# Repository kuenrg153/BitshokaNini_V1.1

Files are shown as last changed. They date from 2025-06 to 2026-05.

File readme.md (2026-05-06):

```
Open Source is Intrinsic to Bitcoin
```
# The Bitshoka Nini V1.1
The Bitshoka Nini V1.1 is based off of the Bitaxe Gamma EXCEPT it uses the KF1950 ASIC from MicroBT / Whatsminer.
Huge shoutout to skot for all the work he did create this ecosystem!
The primary aim Bitshoka Nini is to bring microBT ASICs to the Bitaxe ecosystem. A secondary goal is to make a low cost and readily available Bitaxe variant in Africa.
We hope that this is the first of a number of contributions the Bitshoka team can make to the bitcoin network.
Shoka is "axe" and Nini is "what" in Swahili.

# The bitaxe
bitaxe is a fully open source Bitcoin ASIC miner aimed at decentralizing mining. 

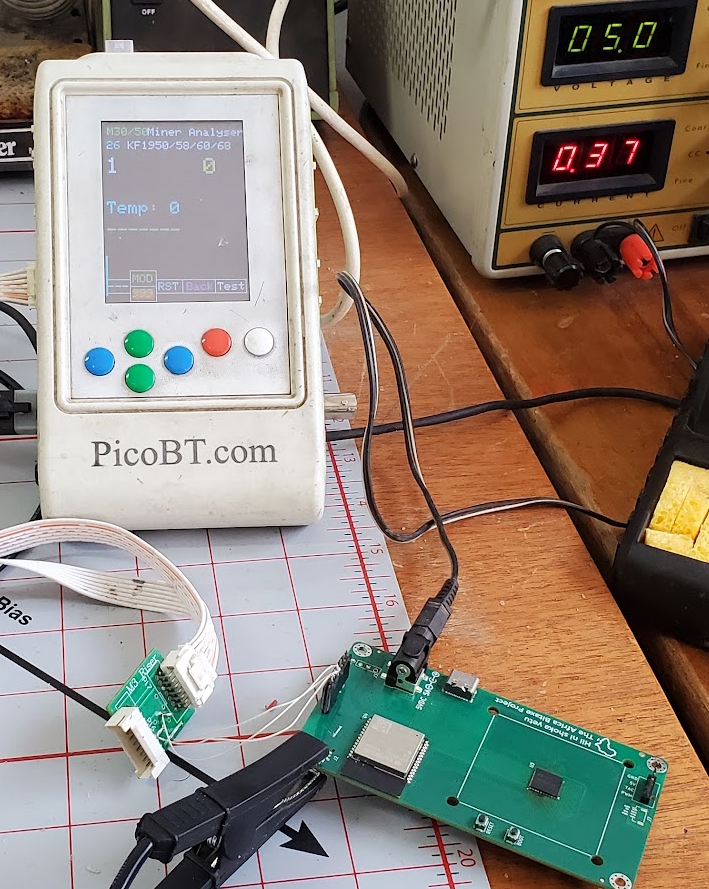
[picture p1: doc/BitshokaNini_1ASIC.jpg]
bitaxeUltra assembled


## Goals
- **Easy**: Just plug it in and mine Bitcoin over WiFi. No external computer needed.
- **Practical**: low cost, low noise, low power, low maintenance. You can run this at home.
- **ASIC Power**: High efficiency and hashrate, based on the latest and greatest Application Specific Integrated Circuits.
- **Versatile**: Mine to any StratumV1 pool, Lottery mine, Solo mine, Or hack it to do whatever you want.
- **Bitcoin Ethos**: Fully open source, permissionless and decentralized to support the worldwide freedom money.

## ASIC
At the heart of the bitaxeGamma is a BM1370 Bitcoin mining ASIC from the Antminer S21 Pro from Bitmain. It's not open source.

- Bitmain claims the BM1370 has 15 J/TH efficiency. We can get pretty close to that with the BitaxeGamma
- The Antminer S21 Pro has a nominal hashrate of 234 TH/s. There are 3 hashboards with 65 chips each, for a total of 195 chips. The bitaxeGamma has a single one of these chips. That means _about_ 1.2 TH/s per bitaxeGamma. Initial testing looks good!
- The BM1370 is brand new and isn't available individually yet. The best place to get these chips is right out of a S21 Pro.
- The BM1370 has a different footprint and pinout from the BM1368, BM1366, BM1397 and BM1387 in previous bitaxe.

## Current Status
- BitaxeGamma 600 is working well and has been released!
- In addition to higher hashrate, the Gamma also uses more power. Please pay attemtion to hash frequency and voltage settings as it's much easier to overheat, especially when using the stock heatsink and fan.
- BM1370 firmware support has been added to [esp-miner](https://github.com/skot/esp-miner)
- Be sure to check the [HW issues](https://github.com/skot/bitaxe/issues) for known bugs, reworks and errata.
- This is an _advanced_ build! You can do it, but if you're not looking for a project, it might be best to buy one pre-assembled from one of the [many sellers](https://bitaxe.org/legit.html). Check [Skot's method](assembly.md) of hand assembling PCBs.

## PCB Hardware
This repo contains all of the design files for the PCB. [KiCAD](https://www.kicad.com) software is used. There is a BOM file for all of the components that get soldered to the PCB. 

- Order PCBs from your favorite PCB shop, like [JLCPCB](https://jlcpcb.com), [SeeedStudio](https://www.seeedstudio.com/fusion_pcb.html), or [PCBWay](https://www.pcbway.com)
    - Gerbers are in the `Manufacturing Files` dir. PCBs are 4-layer, 6mil trace/space and 0.3mm hole compatible. 1oz outer / 0.5oz inner layer thickness works well.
    - Make sure to order stencils too. These are the "paste" layers in the gerbers folder. one for top and one for bottom.
- All PCB parts except the ASIC are available from [DigiKey](https://www.digikey.com/en/products) and others. You can find Digikey part numbers on the DK tab of the BOM

## Extra Hardware
There are a few other hardware components that are needed for a complete bitaxe.

- **Heatsink**
	- [40x40mm heatsink and 5V fan](https://www.aliexpress.com/item/2251832861666365.html) from a random AliExpress seller. The fans are crap, but the heatsinks are good.  
- **Fan**
	- You **must** have active cooling on the bitaxe. The heatsink alone is not enough.
	- The Bitaxe has a connector for a 4pin, 5V PWM fan. 40mm square, 20mm thick fans work nicely with the suggested heatsink. Make sure to get a 5V fan! 12V spin, but slowly overheating your Bitaxe..
	- Upgrade your fan with the [Noctua NF-A4x10](https://noctua.at/en/nf-a4x10-5v-pwm) 5V 4-Pin fan for a much more pleasant experience.
- **Thermal compound**
	- Use a good quality thermal compound between the heatsink and ASIC. [Thermal Grizzly Kryonaut](https://www.amazon.com/Thermal-Grizzly-Kryonaut-Grease-Paste/dp/B011F7W3LU) has been known to work well.  
- **Display**
	- Supports 0.91" SSD1306-based I2C OLED Module. [Example Amazon seller](https://www.amazon.com/gp/product/B08ZY4YBHL). Make sure to get the male pins to interface with the Bitaxe PCB. 
- **Power Supply**
	- **5V DC Only!** Anything else will damage the Bitaxe. Be careful and double-check your power supply is 5V. Many other voltage power supplies use the same connector.
	- The power supply needs to supply in excess of 4A (20W) and not drop below 5V. Often times you have to use a power supply rated for 25-30W to get this!
 		- The [Meanwell GST60A05-P1J](https://www.digikey.com/en/products/detail/mean-well-usa-inc/GST60A05-P1J/7703709) at 30 Watts is the cadillac of 5V PSUs and is working well with the Gamma.  
	- The bitaxe uses a 5.5x2.1mm, center-positive barrel jack. 5.5x2.5mm plugs have been known to work.
- **Stand**
	- The PCB has corner mounting holes. You're going to want a stand to mount your Bitaxe. Many excellent 3D printed designs are available.

## Firmware
- The [ESP-Miner](https://github.com/skot/ESP-Miner) has initial support for the BM1370 ASIC. Improvements are ongoing.

### ESP32 Programming Requirements
- As of the bitaxeUltra, all ESP32 programming is done through a USB-C cable and connector on the bitaxe. See [ESP-Miner](https://github.com/skot/ESP-Miner) for more details.

## More Information
- Project page at [bitaxe.org](https://bitaxe.org)
- [Open Source Miners United](discord.gg/osmu) Discord chat
- [building.md](building.md) for PCB ordering tips
- [assembly.md](assembly.md) for assembly tips

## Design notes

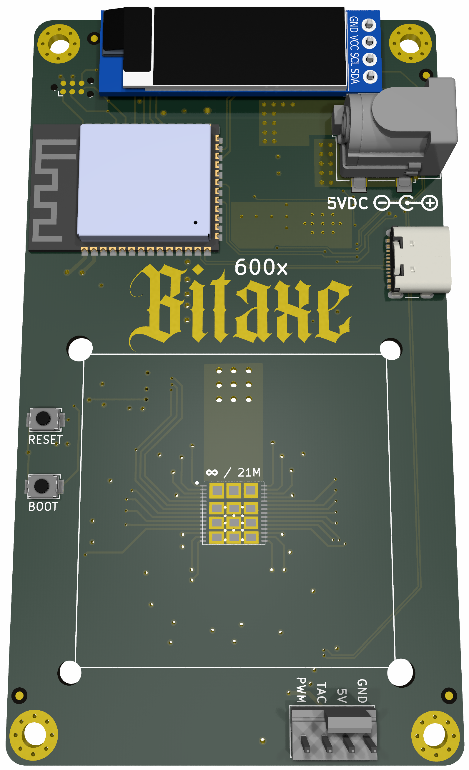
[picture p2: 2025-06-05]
doc/render.png

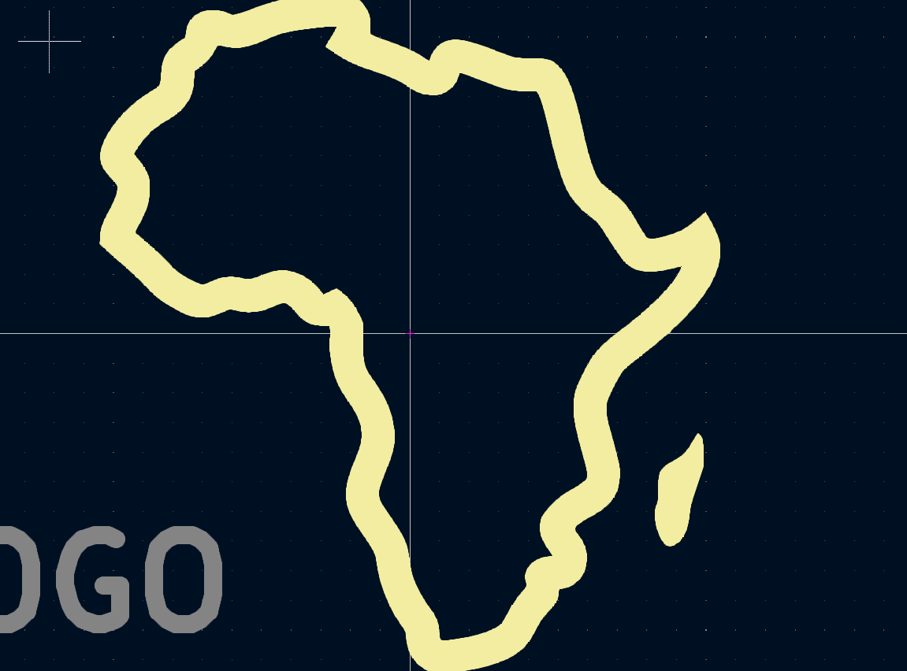
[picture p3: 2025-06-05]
Africa Map Only.png

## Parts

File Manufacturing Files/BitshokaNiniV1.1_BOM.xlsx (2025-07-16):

Comment | Reference | Footprint | PARTNO
0 | R6 R10 R17 R19 R20 R26 R27 R75 R76 R77 R78 R79 | Resistor_SMD:R_0402_1005Metric | CSR1206FT1R00
0 | R35 R73 | Resistor_SMD:R_0402_1005Metric | DNP
100pF | C13 | Capacitor_SMD:C_0402_1005Metric | 885012005013
470pF | C50 | Capacitor_SMD:C_0402_1005Metric | CL05B471KB5NNNC
1000pF | C11 | Capacitor_SMD:C_0402_1005Metric | CC0805KRX7R9BB102
2200pF | C9 | Capacitor_SMD:C_0402_1005Metric | GRM155R61H222KA01D
4700pF | C6 | Capacitor_SMD:C_0402_1005Metric | GRM155R71E472KA01D
72nH | L1 | FP0805R1 | FP0805R1-R07-R
0.1uF | C8 C25 C27 C28 C29 C31 C32 C34 C37 C38 C47 C49 C52 C53 C73 C74 | Capacitor_SMD:C_0402_1005Metric | CL05A104KO5NNNC
0.1uF | C12 | Capacitor_SMD:C_0603_1608Metric | CL05A104KO5NNNC
1uF | C1 C5 C7 C21 C22 C23 C26 C30 C39 C40 | Capacitor_SMD:C_0402_1005Metric | EMK105BJ105MV-F
4.7uF | C10 | Capacitor_SMD:C_0402_1005Metric | GRM155R61A475MEAAD
10uF | C2 C24 C33 | Capacitor_SMD:C_0805_2012Metric | CL21A106KOQNNNE
47uF | C3 C4 C51 | Capacitor_SMD:C_1210_3225Metric | CL32A476KOJNNNE
100uF | C14 C15 C16 C17 C43 | Capacitor_SMD:C_1206_3216Metric | GRM32EC80J107ME20L
100uF | C35 | Capacitor_SMD:C_1206_3216Metric | DNP
560uF | C18 C19 C20 C72 | EEF-GX | EEF-GX0D561R
1 | R12 | Resistor_SMD:R_1206_3216Metric | CSR1206FT1R00
10 | R11 | Resistor_SMD:R_0402_1005Metric | RC0402FR-0710RL
27 | R34 | Resistor_SMD:R_0402_1005Metric | RC0402JR-0727RL
33 | R33 | Resistor_SMD:R_0402_1005Metric | RC0402FR-1333RL
49.9 | R13 R14 | Resistor_SMD:R_0402_1005Metric | RC0402FR-0749R9L
100 | R18 R22 R23 | Resistor_SMD:R_0402_1005Metric | RC0402FR-07100RL
332 | R31 | Resistor_SMD:R_0402_1005Metric | RC0402FR-07332RL
402 | R32 | Resistor_SMD:R_0402_1005Metric | RC0402FR-07402RL
442 | R28 | Resistor_SMD:R_0402_1005Metric | RT0402BRD07442RL
499 | R30 | Resistor_SMD:R_0402_1005Metric | RC0402FR-07499RL
549 | R29 | Resistor_SMD:R_0402_1005Metric | RC0402FR-07549RL
1k | R38 | Resistor_SMD:R_0402_1005Metric | RC0402FR-071KL
3.74k | R8 | Resistor_SMD:R_0402_1005Metric | RC0402FR-073K74L
4.64k | R1 R5 R39 R40 R80 R81 R82 | Resistor_SMD:R_0402_1005Metric | RC0402FR-074K64L
5.6k | R24 | Resistor_SMD:R_0402_1005Metric | RC0402FR-135K6L
10k | R15 R16 R21 R25 R36 R37 R72 | Resistor_SMD:R_0402_1005Metric | RC0402FR-0720KL
11.8k | R9 | Resistor_SMD:R_0402_1005Metric | RC0402FR-0711K8L
40.2k | R74 | Resistor_SMD:R_0402_1005Metric | RC0402JR-0710KL
24MHz | U7 | SMD3225-4P | SX3M25.000E20F30THN
54-00164 | J1 | TENSILITY_54-00164 | 54-00164
Conn_01x04 | J6 | 470531000 | 470531000
Conn_01x04 | J7 | Connector_JST:JST_SH_BM04B-SRSS-TB_1x04-1MP_P1.00mm_Vertical
EMC2101 | U10 | Package_SO:TSSOP-8_3x3mm_P0.65mm | EMC2101-R-ACZL-TR
ESP32-S3-WROOM-1 | U4 | ESP32-S3-WROOM-1 | ESP32-S3-WROOM-1-N16R8
GT-TC029B-H025-L1N | SW1 SW2 | SW_CS1213AGF260_CRS | CS1213AGF260
LM358 | U23 | Package_SO:TSSOP-8_4.4x3mm_P0.65mm | LM358LVIPWR
MMBT2222A | Q4 | Package_TO_SOT_SMD:SOT-23 | MMBT2222A
MMBT3906 | Q1 Q3 | Package_TO_SOT_SMD:SOT-23 | MMBT3906
RT9080-33GJ5 | U3 | RT9080-33GJ5 | RT9080-33GJ5
SN74AVC4T774 | U9 | Package_SO:TSSOP-16_4.4x5mm_P0.65mm | SN74AVC4T774PWR
SPX3819M5-L-1-8 | U5 | Package_TO_SOT_SMD:SOT-23-5 | SPX3819M5-L-1-8
TPS546D24ARVFR | U2 | LQFN40-CLIP | TPS546D24ARVFR
USB_C_Receptacle_USB2.0 | J5 | USB_C_Receptacle_GCT_USB4105-xx-A | USB4105-GF-A
~ | U8 | KF1950 | DNP

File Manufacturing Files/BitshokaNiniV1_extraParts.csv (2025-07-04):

Designator | Footprint | Quantity | VALUE | PARTNO | DK
+ACI-C18 | C20 | C19 | C72+ACI- | EEF+AC0-GX | 4 | 560uF | EEFGX0D561R | PCE5057CT+AC0-ND
L1 | SLC1049 | 1 | 75nH | SLC1049+AC0-750MLB
R74 | R+AF8-0402+AF8-1005Metric | 1 | 40.2k | RC0402FR+AC0-0740K2L | 311+AC0-40.2KLRCT+AC0-ND
+ACI-R21 | R72 | R36 | R25 | R37 | R15 | R16+ACI- | R+AF8-0402+AF8-1005Metric | 7 | 10k | RC0402FR+AC0-1310KL | 13+AC0-RC0402FR+AC0-1310KLCT+AC0-ND
+ACI-R80 | R1 | R5 | R82 | R81+ACI- | R+AF8-0402+AF8-1005Metric | 7 | 4.64k | RC0402FR+AC0-074K64L | 311+AC0-4.64KLRCT+AC0-ND
R33 | R+AF8-0402+AF8-1005Metric | 1 | 33 | RC0402FR+AC0-1333RL | 13+AC0-RC0402FR+AC0-1333RLCT+AC0-ND
R29 | R+AF8-0402+AF8-1005Metric | 1 | 549 | RC0402FR+AC0-07549RL | 311+AC0-549LRCT+AC0-ND
R31 | R+AF8-0402+AF8-1005Metric | 1 | 332 | RC0402FR+AC0-07332RL | 311+AC0-332LRCT+AC0-ND
Q4 | SOT+AC0-23 | 1 | MMBT2222A | MMBT2222A | 3372+AC0-MMBT2222ATR+AC0-ND
R30 | R+AF8-0402+AF8-1005Metric | 1 | 499 | RC0402FR+AC0-07499RL | 311+AC0-499LRCT+AC0-ND
U7 | SMD3225+AC0-4P | 1 | 24MHz | SX3M24.000E20F30THN | 5852+AC0-SX3M24.000E20F30THNTR+AC0-ND
C12 | C+AF8-0603+AF8-1608Metric | 1 | 0.1uF | CL10B104KA8NNNC | 1276+AC0-1006+AC0-1+AC0-ND
U5 | SOT+AC0-23+AC0-5 | 1 | SPX3819M5+AC0-L+AC0-1+AC0-8 | SPX3819M5+AC0-L+AC0-1+AC0-8 | 1016+AC0-1411+AC0-ND
+ACI-Q3 | Q1+ACI- | SOT+AC0-23 | 2 | MMBT3906 | MMBT3906 | 3372+AC0-MMBT3906TR+AC0-ND
U9 | TSSOP+AC0-16+AF8-4.4x5mm+AF8-P0.65mm | 1 | SN74AVC4T774 | SN74AVC4T774PWR | 296+AC0-24739+AC0-1+AC0-ND
R34 | R+AF8-0402+AF8-1005Metric | 1 | 27 | RC0402JR+AC0-0727RL | 311+AC0-27JRCT+AC0-ND
R28 | R+AF8-0402+AF8-1005Metric | 1 | 442 | RT0402BRD07442RL | YAG4265CT+AC0-ND
R32 | R+AF8-0402+AF8-1005Metric | 1 | 402 | RC0402FR+AC0-07402RL | YAG3152CT+AC0-ND
U23 | TSSOP+AC0-8+AF8-4.4x3mm+AF8-P0.65mm | 1 | LM358 | LM358LVIPWR | 296+AC0-51268+AC0-1+AC0-ND
U8 | KF1950 | 1 | +AH4-

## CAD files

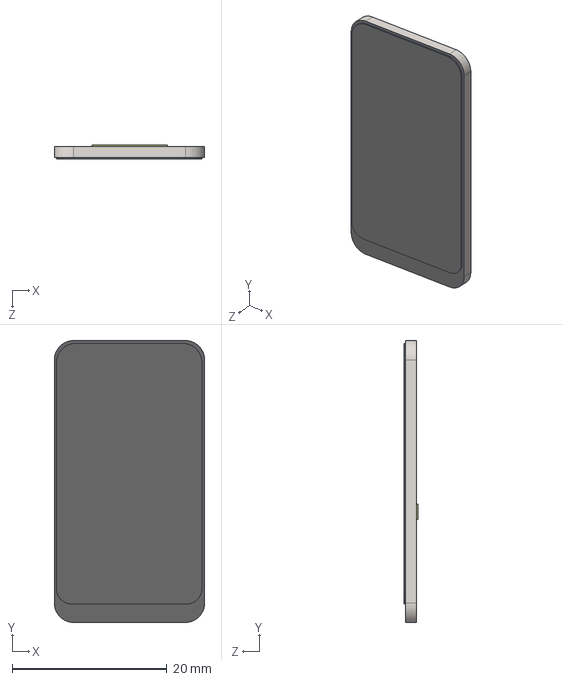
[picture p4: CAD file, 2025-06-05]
3d/DISST7789-176x320.STEP
19.4 x 36.4 x 1.86 mm

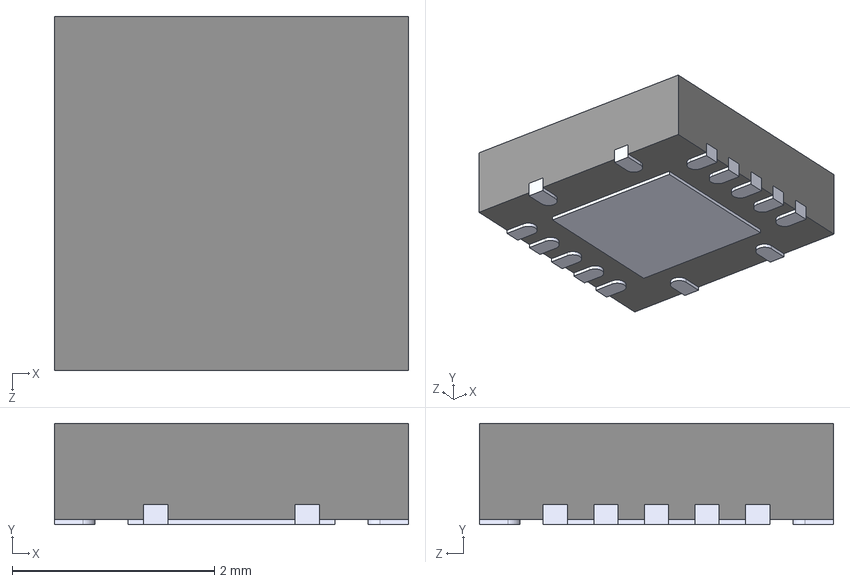
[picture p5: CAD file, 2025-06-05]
3d/TXB0104RGYR.STEP
3.50 x 1.00 x 3.50 mm

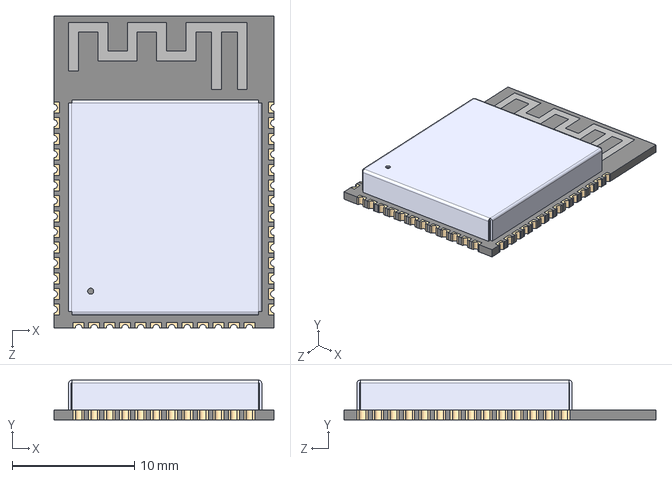
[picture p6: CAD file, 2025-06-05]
3d/ESP32-S3-WROOM-1-N8R2--3DModel-STEP-56544.STEP
18.0 x 3.25 x 25.5 mm

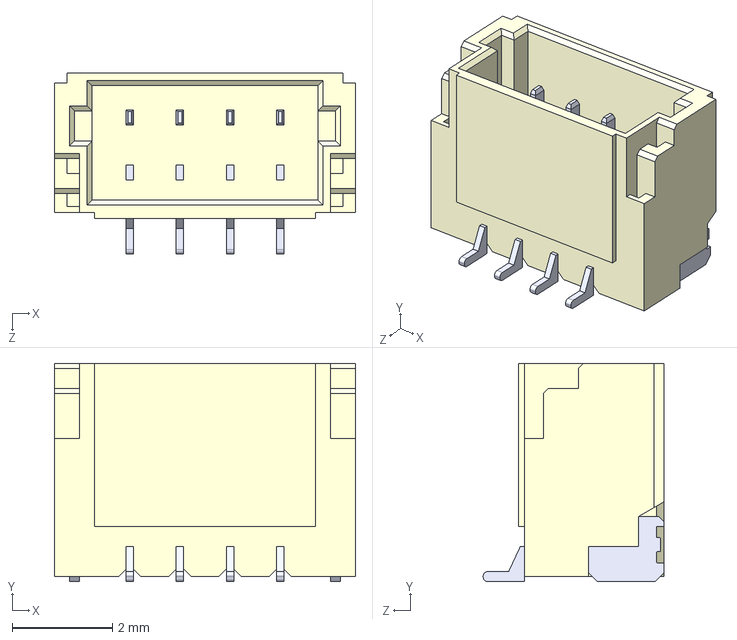
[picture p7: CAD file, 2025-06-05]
3d/BM04B-SRSS-TBT(LF)(SN)--3DModel-STEP-56544.STEP
6.00 x 4.35 x 3.60 mm

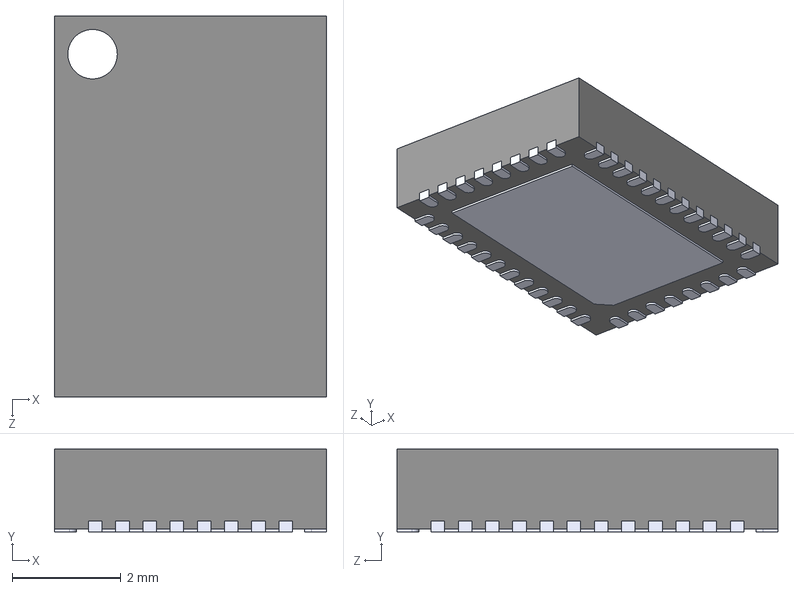
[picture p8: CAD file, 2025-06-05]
3d/TPS546D24ARVFR.step
5.00 x 1.52 x 7.00 mm

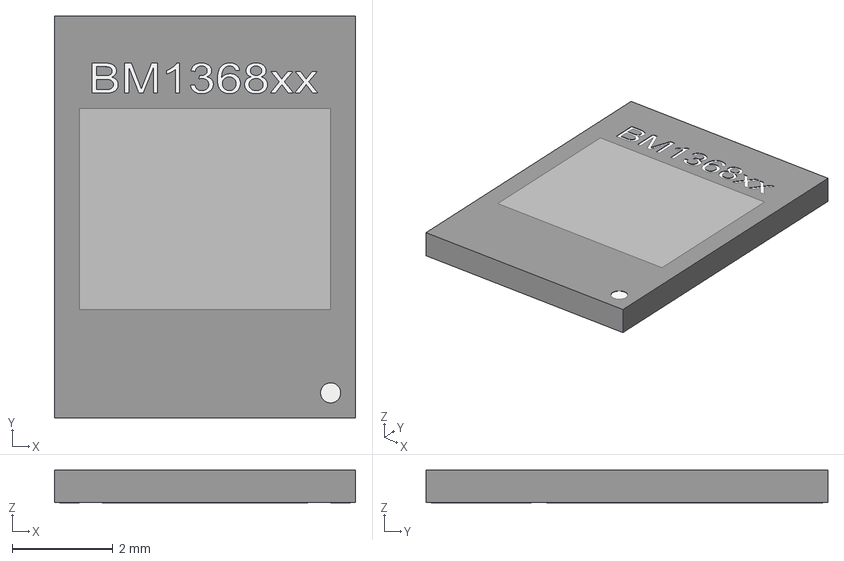
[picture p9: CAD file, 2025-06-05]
3d/BM1368xx.stp
6.00 x 8.00 x 0.65 mm

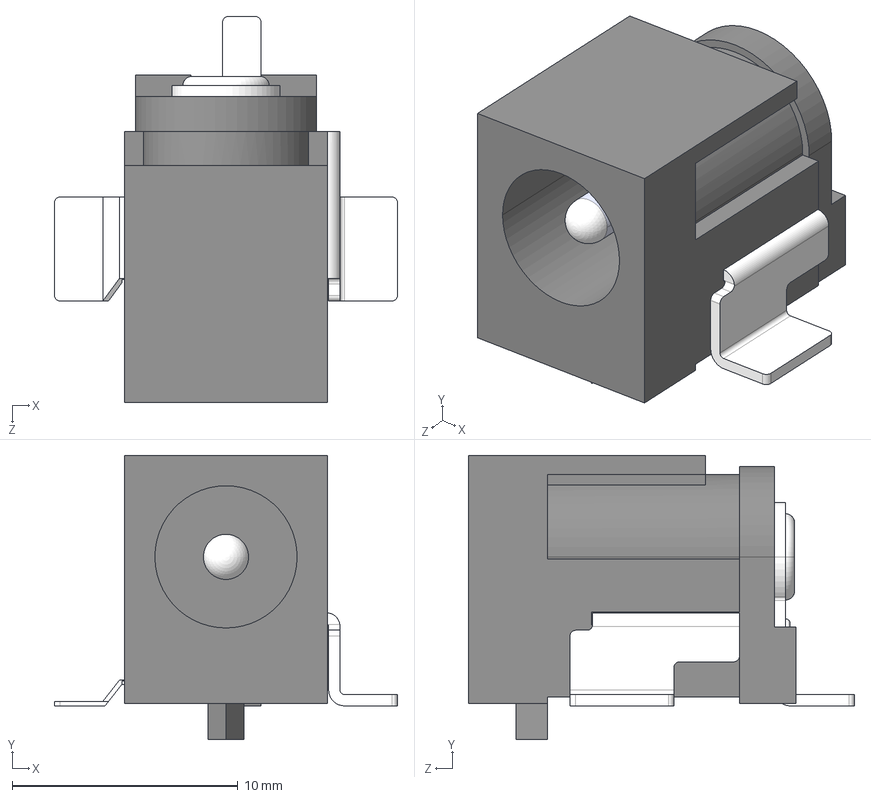
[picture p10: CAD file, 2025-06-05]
3d/CUI_DEVICES_PJ-036AH-SMT-TR.step
15.2 x 12.6 x 17.1 mm

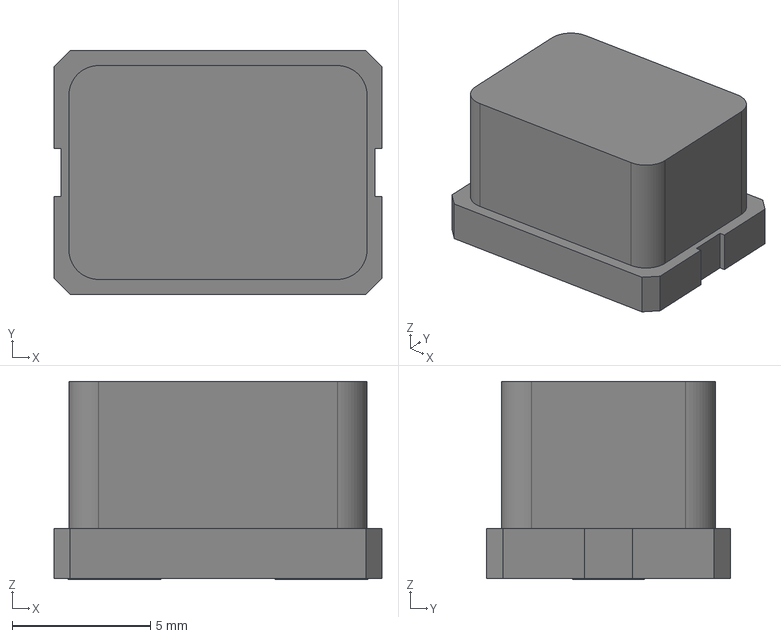
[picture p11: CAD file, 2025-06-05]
3d/SLC1175-271MEC_COC.step
11.9 x 8.83 x 7.19 mm

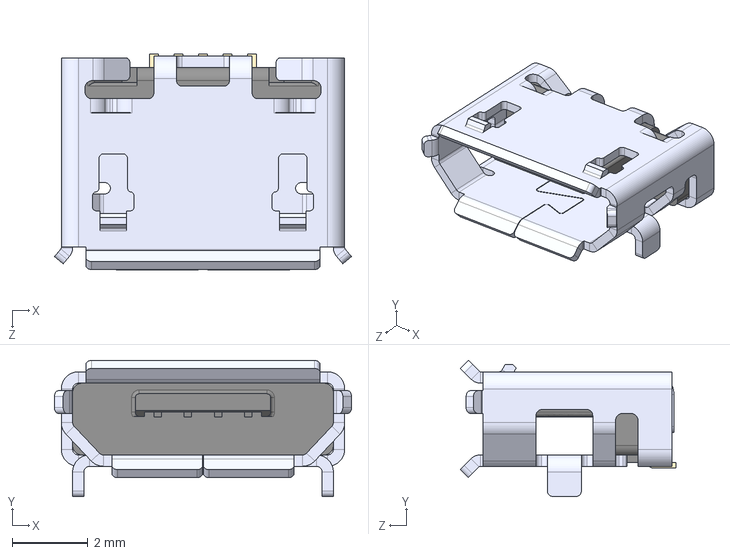
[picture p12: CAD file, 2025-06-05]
3d/USB_10118193-0001LF.STEP
7.86 x 3.60 x 5.71 mm

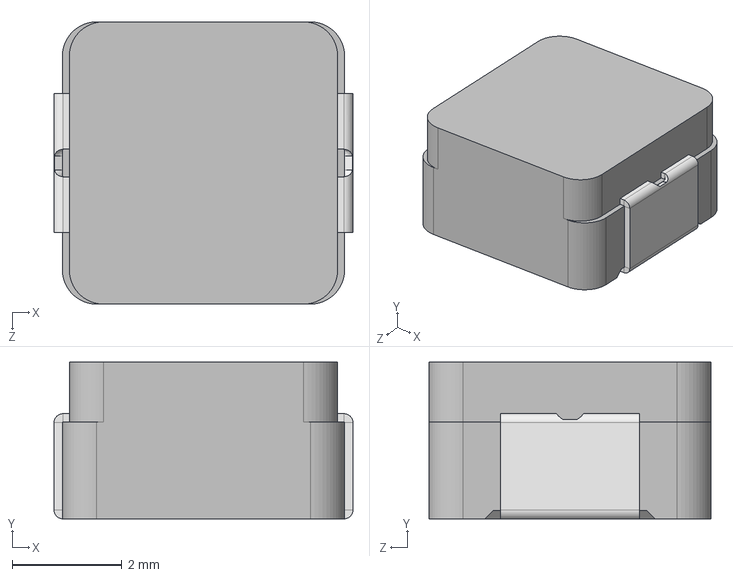
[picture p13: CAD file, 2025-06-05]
3d/IHLP2020CZ.step
5.45 x 2.86 x 5.15 mm

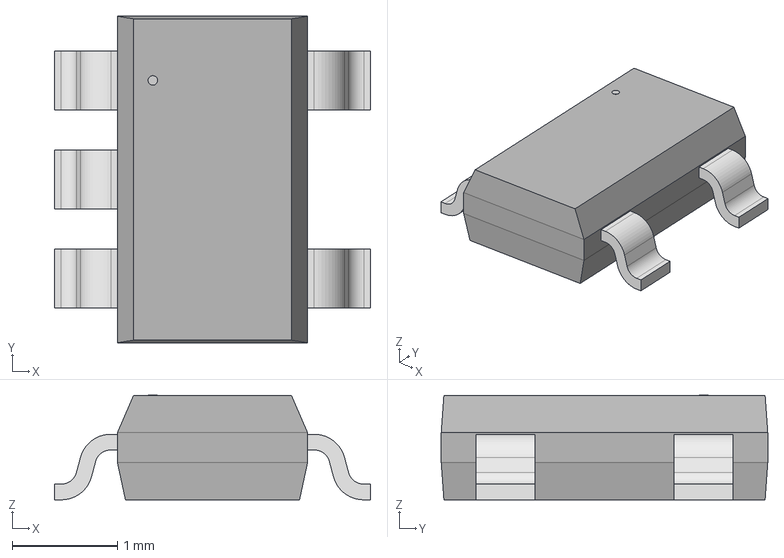
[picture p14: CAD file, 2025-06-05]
3d/TSOT-23-5_RIT.step
3.00 x 3.10 x 0.993 mm

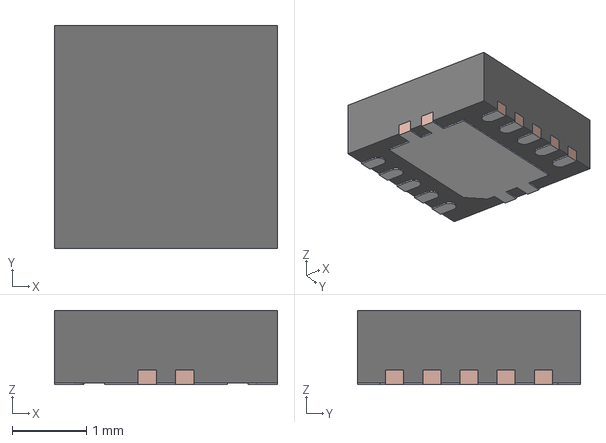
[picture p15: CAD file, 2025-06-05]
3d/DRC0010J.stp
3.00 x 3.00 x 1.00 mm
BODY-SON
FRAME-DRC0010J

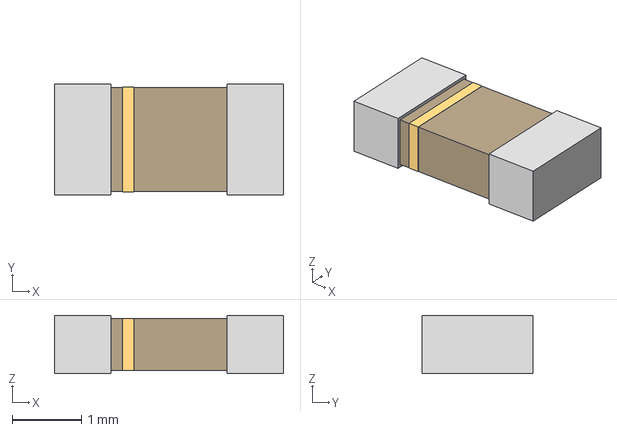
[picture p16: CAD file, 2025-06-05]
3d/XTAL_SC32S-7PF20PPM_EPS.step
3.30 x 1.60 x 0.838 mm

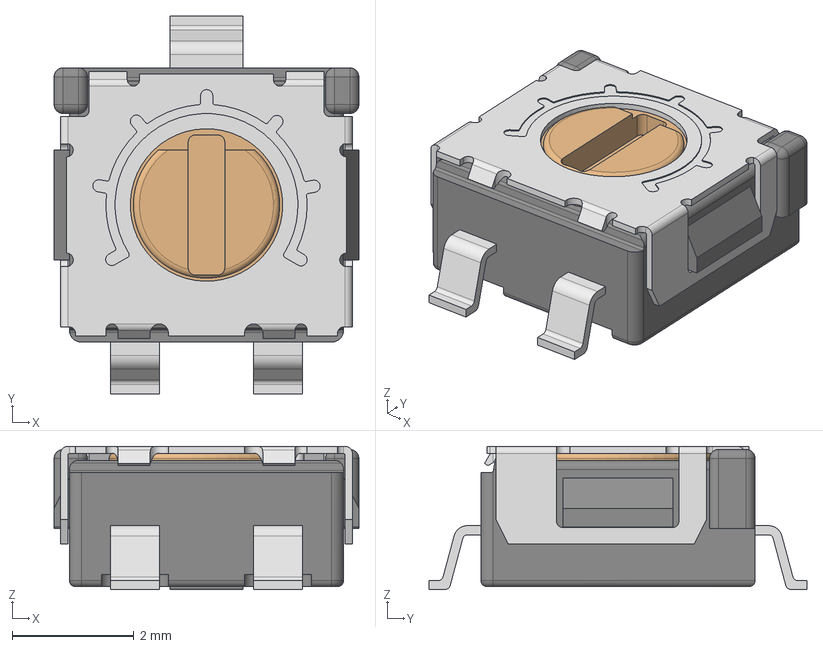
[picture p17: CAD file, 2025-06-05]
3d/ST-4ETB2k_(202).stp
5.00 x 6.20 x 2.35 mm
ST-4EB_terminal_2
ST-4EB_terminal
ST-4EB_terminal_1
ST-4-dial2
ST-4EB10X(100)_body

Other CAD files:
3d/SOT-23-5_M5_MCH.step
3d/DQH0008A.stp
3d/Bitaxe_Heatsink.step
3d/oscillator3.2x2.5.step
3d/21-0164B_L622-1_MXM.step
3d/2R5TPE220MAFB.step
3d/470531000.stp
3d/54-00164.STEP
3d/CS1213AG-tr.stp
3d/CUI_DEVICES_PJ-002AH.step
3d/CUI_DEVICES_PJ-037AH.step
3d/CX3225SB16000H0FLJCC.STEP
3d/Coilcraft-SLC1175.STEP
3d/Cree_PLCC6.stp
3d/DQG0008A.stp
3d/DRL0006A.stp
3d/FP1006V2-R.STEP
3d/FTSH-105-01-F-DV-K.stp
3d/OLED_0.91_128x32.stp
3d/PLCC6_LED_3_5X3_4X2_8_CRW.step
3d/SMV_z90.stp
3d/SN74AXC1T45DBVR.STEP
3d/SW_CS1213AGF260_CRS.step
3d/XRCGB27M120F3M10R0_MUR.step
3d/c-63862-1-r-3d.stp

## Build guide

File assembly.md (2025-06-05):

- Get a convection toaster oven. Nothing fancy, it just has a fan inside for more even heating. Never use this oven for food.
  - [BLACK+DECKER TO3250XSB 8-Slice Extra Wide Convection Countertop Toaster Oven, Includes Bake Pan, Broil Rack & Toasting Rack, Stainless Steel/Black](https://www.amazon.com/BLACK-DECKER-TO3250XSB-Convection-Countertop/dp/B00LU2I428)
- Get a thermocouple thermometer. Make sure the probe and probe jacket can go to ~300C
  - [Digital Thermocouple Temperature Thermometer, PEAKMETER PM6501 K Type LCD Thermometer Testing Tool Celsius and Fahrenheit](https://www.amazon.com/Thermocouple-Temperature-Thermometer-PEAKMETER-Fahrenheit/dp/B08L11MMFM)
- Use Sn63/Pb37 no-clean, leaded, solder paste. Keep it in the refrigerator so it's nice and cold before you stencil it. (obvs don't get it near your food). Wash your hands well after.
  - [Chip Quik SMD291AX50T3 Solder Paste in jar 50g (T3) Sn63/Pb37 no clean](https://www.amazon.com/gp/product/B07BH5LP5G)
- Take your time to get the paste stenciled right. Don't be afraid to wipe it off with IPA and try again. The paste stencils better when it's cold.
- Use tweezers to put all of the parts on the pasted board. I like the curved Aven Technik 7-SA Tweezers. I have also been known to wear a dorky magnifier headset.
  - [Aven 18072ARS 7-SA Style Artis Tweezer, Black with Yellow Print](https://www.amazon.com/Aven-18072ARS-Style-Tweezer-Yellow/dp/B01D4R1OXW)
  - [Headband Magnifier Hands Free Jeweler Loupe Head Mount Magnifying Headset Visor Double Optical Glass 4 Replaceable Lenses for Reading,Repair(1.5X,2.0X,2.5X,3.5X)](https://www.amazon.com/Headband-Magnifier-Jeweler-Magnifying-Replaceable/dp/B08RYVH7DL)
- Put the board(s) in the toaster oven. I usually put them right on the wire rack, which is in the metal tray.
- Put the thermocouple inside the toaster oven. Close the door on the thermocouple wire so that it holds the end right above the PCB, inside the oven.
- Turn the oven on convection bake, medium setting. The convection fan in the toaster oven helps keep the temperature even through out the inside of the oven.
- Once the temp (as read off the thermocouple thermometer) gets to 140C, turn down the oven heat and try and keep it at 140-150C for 2 minutes. Open the door a little if it's getting to hot. This is the "Soak" phase
- After two minutes, turn the heat to high
- Once the temp reaches 200C start a timer for 30 seconds. Keep the temp between 200 and 220C for this phase. Usually you don't need to do anything. This is the "Reflow" phase. You should see all of the paste melt.
- After 30 seconds, turn off the toaster oven. open the door.
- Let the boards cool for a bit in the oven with the door open.
- Once cool to touch, inspect the boards with a microscope for dry pads and/or bridges. Depending on how well you did with stenciling there may be a few, especially on QFP packages. QFNs sometimes too. Fix these up with paste flux, solder braid and your soldering iron.
- If you have parts on both sides of the board, it's fine to just repeat the steps on the second side. The surface tension of the solder almost always keeps the parts from falling off while they are getting reflowed upside down. When you reflow the second side, make a little stand out of metal to keep the bottom side parts off the wire rack in the toaster oven.

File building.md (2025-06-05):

# Building PCBs

In order to get PCBs made, you usually need to provide them with the following files;

- Gerbers
- Drill Files

Additionally if you want to have a shop assemble the boards for you, you’ll also need to provide;

- Bill of Materials (BOM)
- Centroid file (XY)

### Generating Gerbers and Drill Files

Gerbers are a set of files in a standard format that allow a PCB manufacturer to build the PCB. Usually there is one gerber file for each layer of a PCB. A Gerber file can represent a wide variety of different layer types;

- Copper layer
- Silkscreen Layer
- Soldermask layer
- Board outline
- Drills (Okay, this is actually not a gerber, but your PCB house will definitely need it)

Any* PCB CAD software will allow you to generate gerbers. We use [KiCad](https://www.kicad.org) because it is open source, free, and *awesome*. Here is how to generate gerbers in KiCad v6;

1. Open up the design in KiCad and switch to the PCB board editor view (ie not the schematic). Some people call this pcbnew.
2. Choose File → Fabrication Outputs → Gerbers (.gbr)…
3. Pick the right options for what your PCB board house expects. Here is what I use;

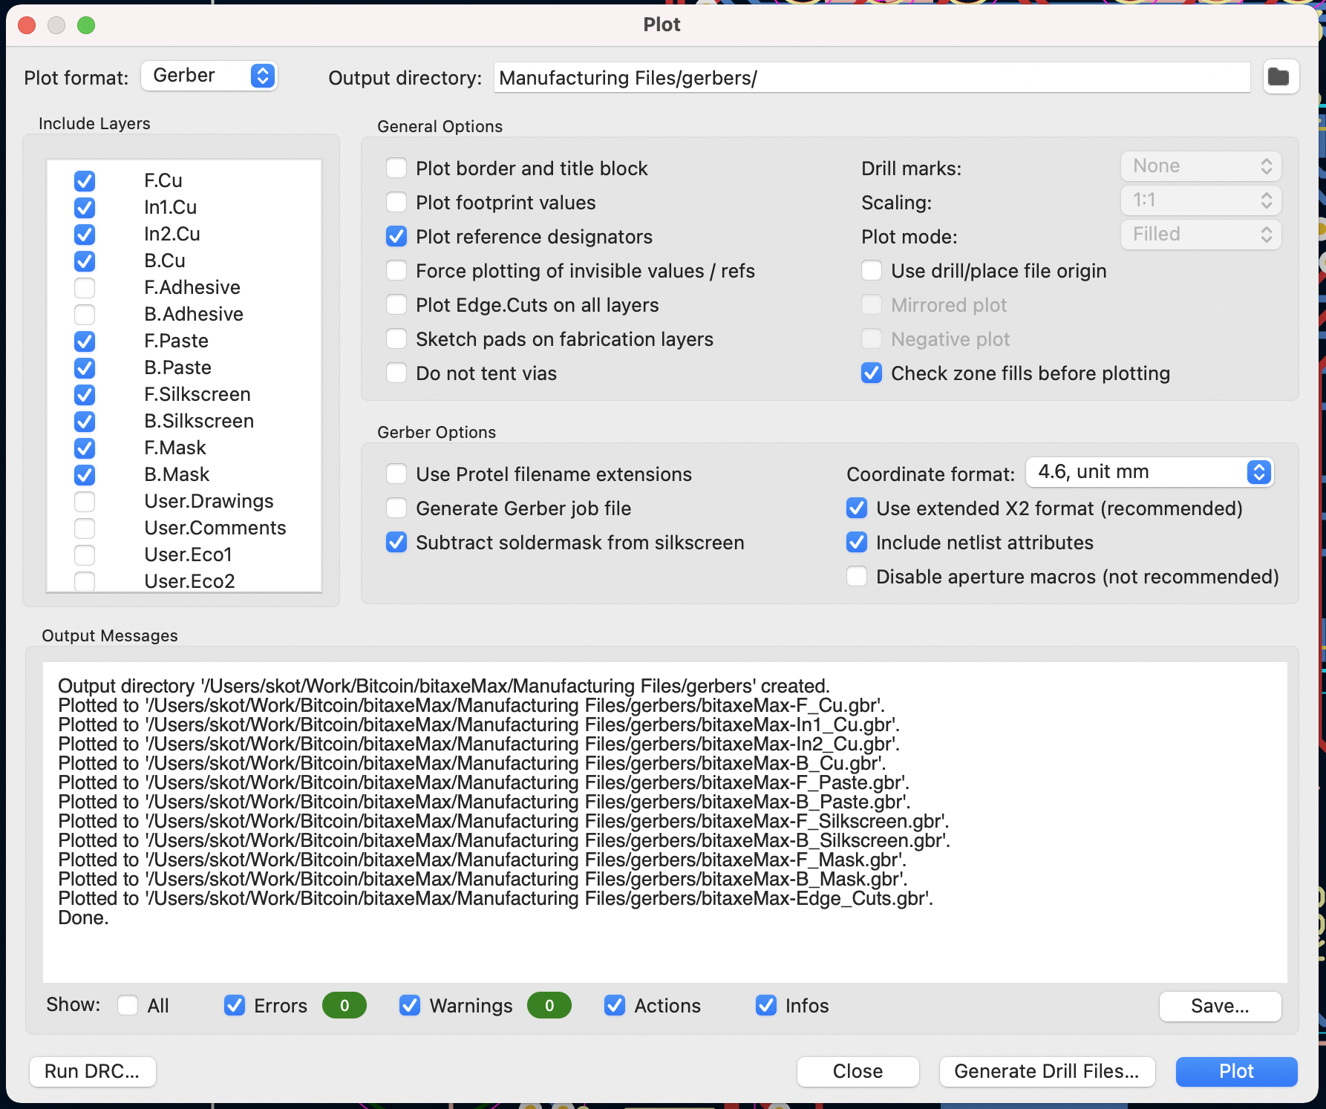
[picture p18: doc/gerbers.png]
Gerber Plot Window


Make sure you have these “Include Layers” checked;

- **F.Cu** → Front copper
- **In1.Cu** → Inner layer 1 Copper
- **In2.Cu** → Inner layer 2 Copper
- **B.Cu** → Back copper
- **F.Paste** → Front Paste. Note: this is used to make a solder paste stencil. This is optional. Many PCB houses will let you order stencils as a separate step. use these gerbers for ordering a stencil
- **B.Paste** → Back paste. see note above
- **F.Silkscreen** → Front Silkscreen. sometimes this is called the Legend
- **B.Silkscreen** → Back Silkscreen. sometimes this is called the Legend of Zelda
- **F.Mask** → Front soldermask
- **B.Mask** → Back soldermask
- **Edge.Cuts** → The board outline. This defines the shape the PCB is cut to.

1. Next you’ll want to generate the drill files. Click that button in the lower right corner of the “Plot” screen from above.
2. Generate the drill files according to your PCB house specs. Here are the options I use;

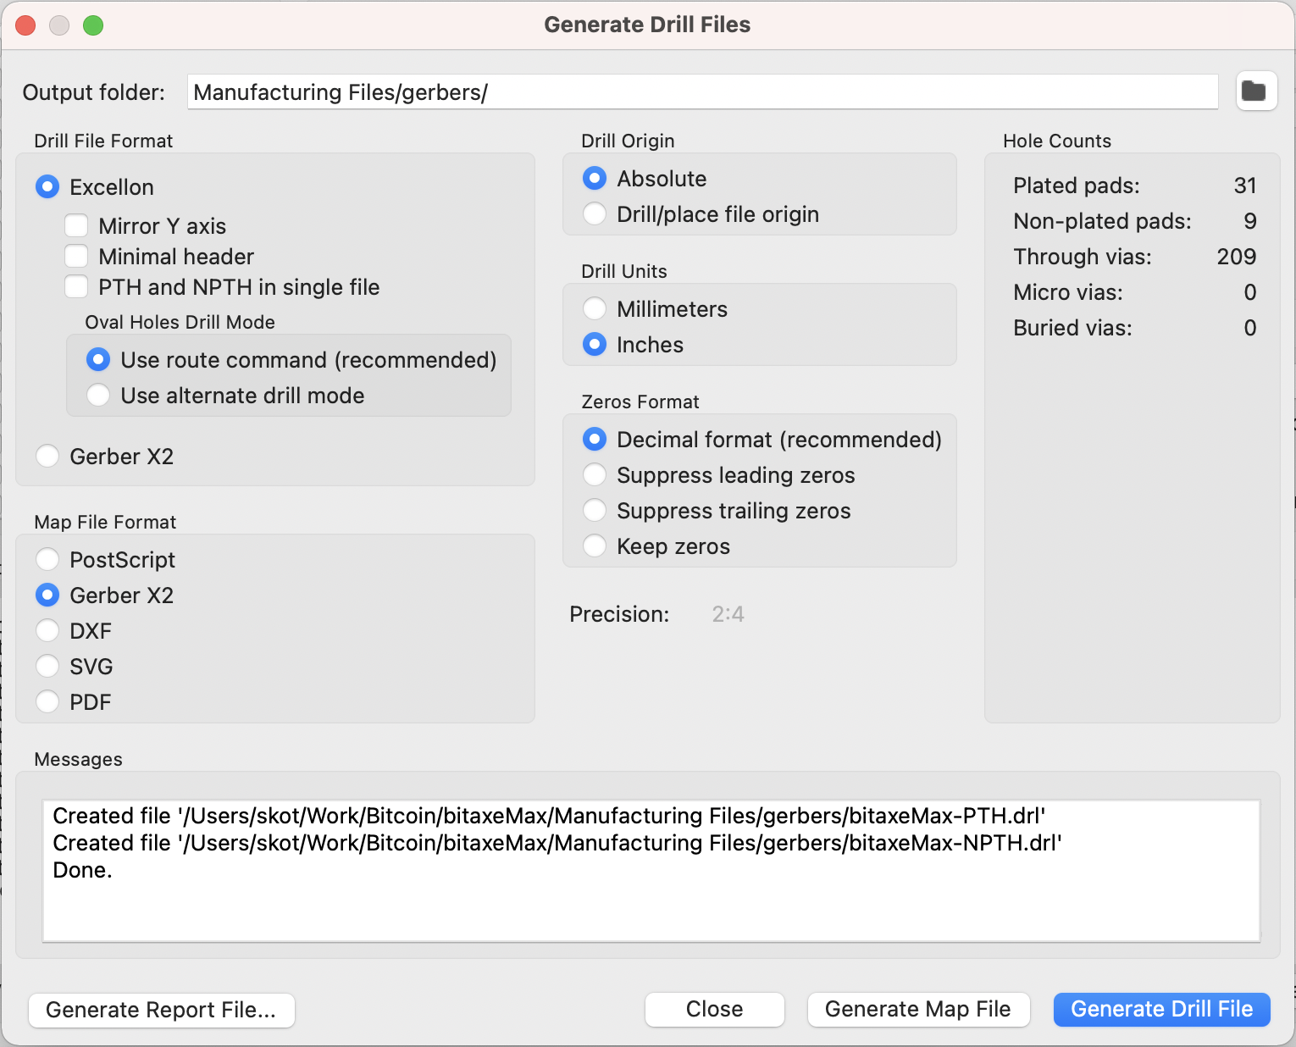
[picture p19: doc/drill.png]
Drill Files Window


That’s it! Take all of those generated files and give them to your PCB house. If you’re ordering stencils (which you should!), pull out `-F_Paste.gbr` and `-B_Paste.gbr` and send those to the right place. Paste gerbers are not needed to manufacture a PCB.

### Generating PCBA Manufacturing files

- TBD

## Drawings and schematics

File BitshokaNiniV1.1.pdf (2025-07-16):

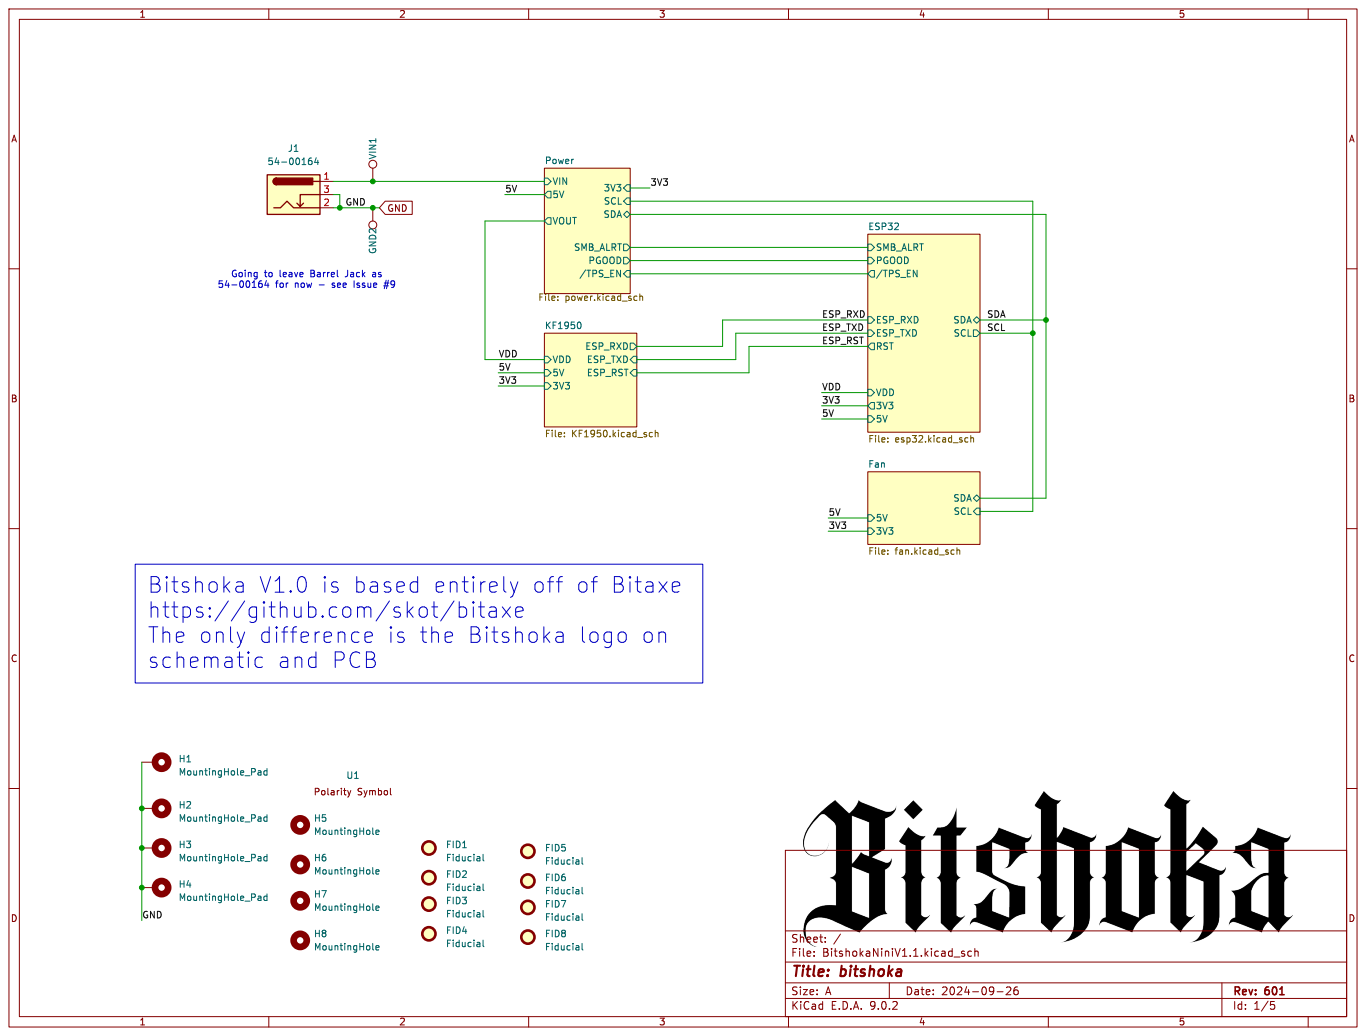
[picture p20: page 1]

3V3 Fan File: fan.kicad_sch VOUT VIN

ESP_TXD Bitshoka V1.0 is based entirely off of Bitaxe

https://github.com/skot/bitaxe

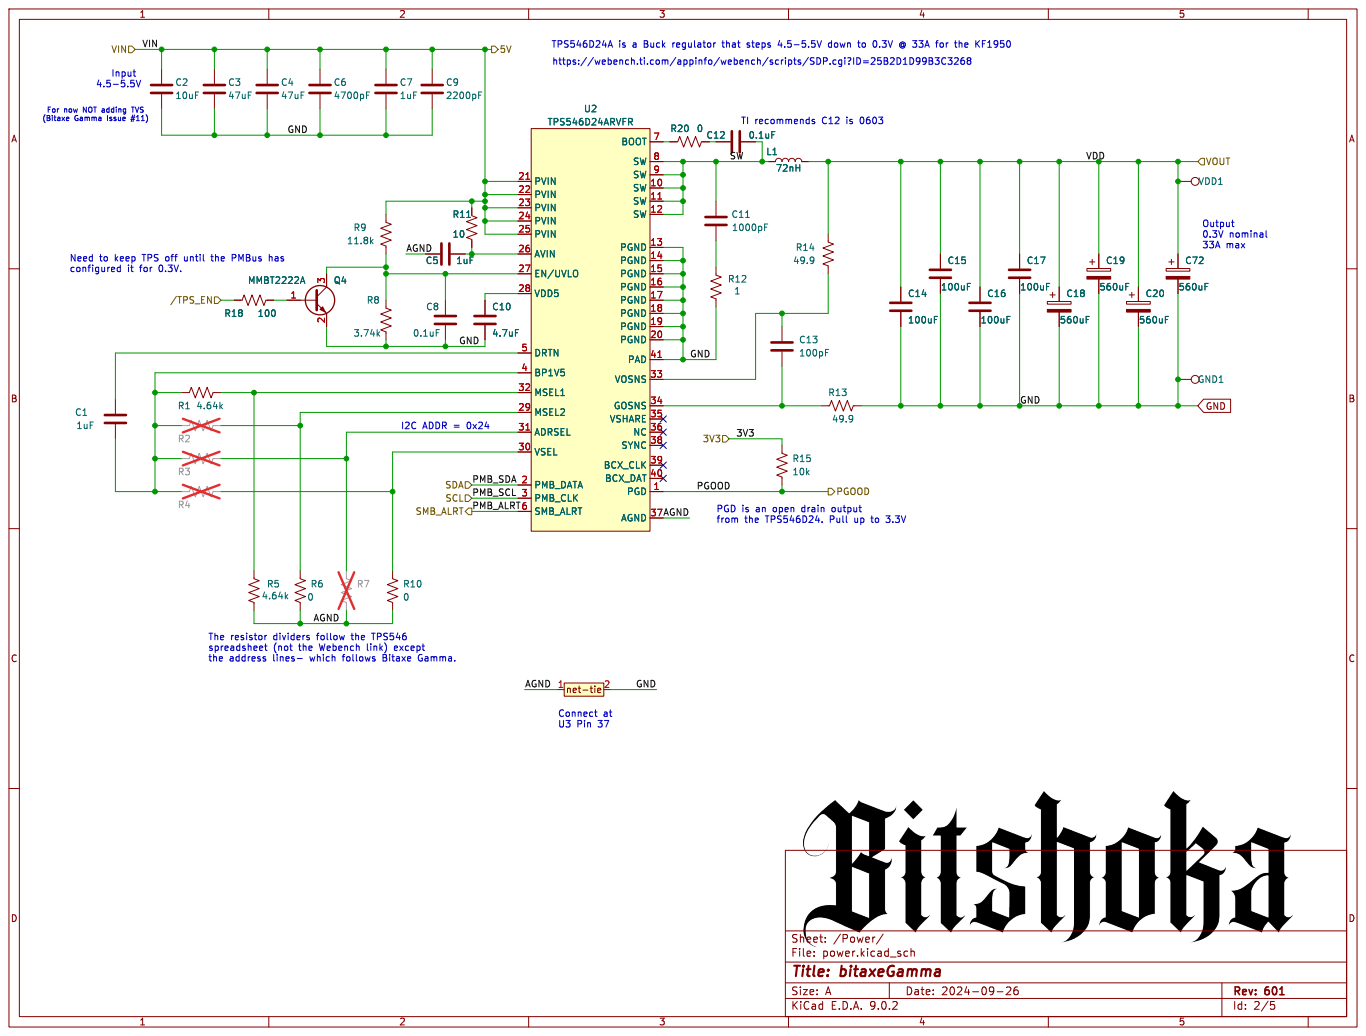
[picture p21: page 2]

For now NOT adding TVS

from the TPS546D24. Pull up to 3.3V Connect at U3 Pin 37

File: power.kicad_sch Sheet: /Power/
Id: 2/5 Title: bitaxeGamma

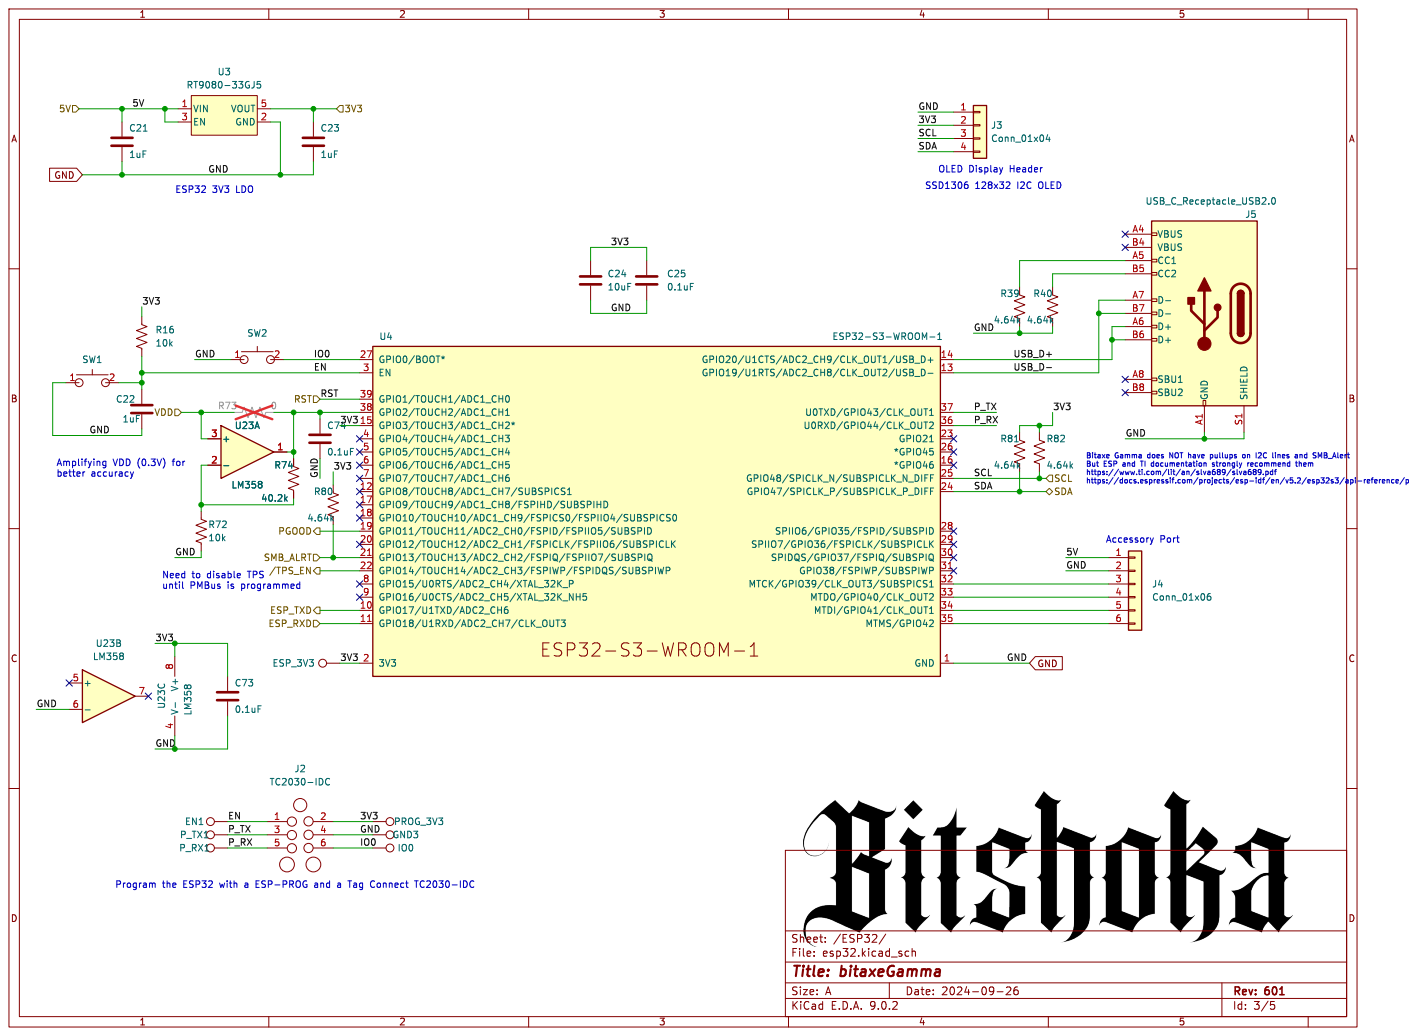
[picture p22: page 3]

https://www.ti.com/lit/an/slva689/slva689.pdf https://docs.espressif.com/projects/esp-idf/en/v5.2/esp32s3/api-reference/peripherals/i2c.html ESP32 3V3 LDO

Need to disable TPS
until PMBus is programmed

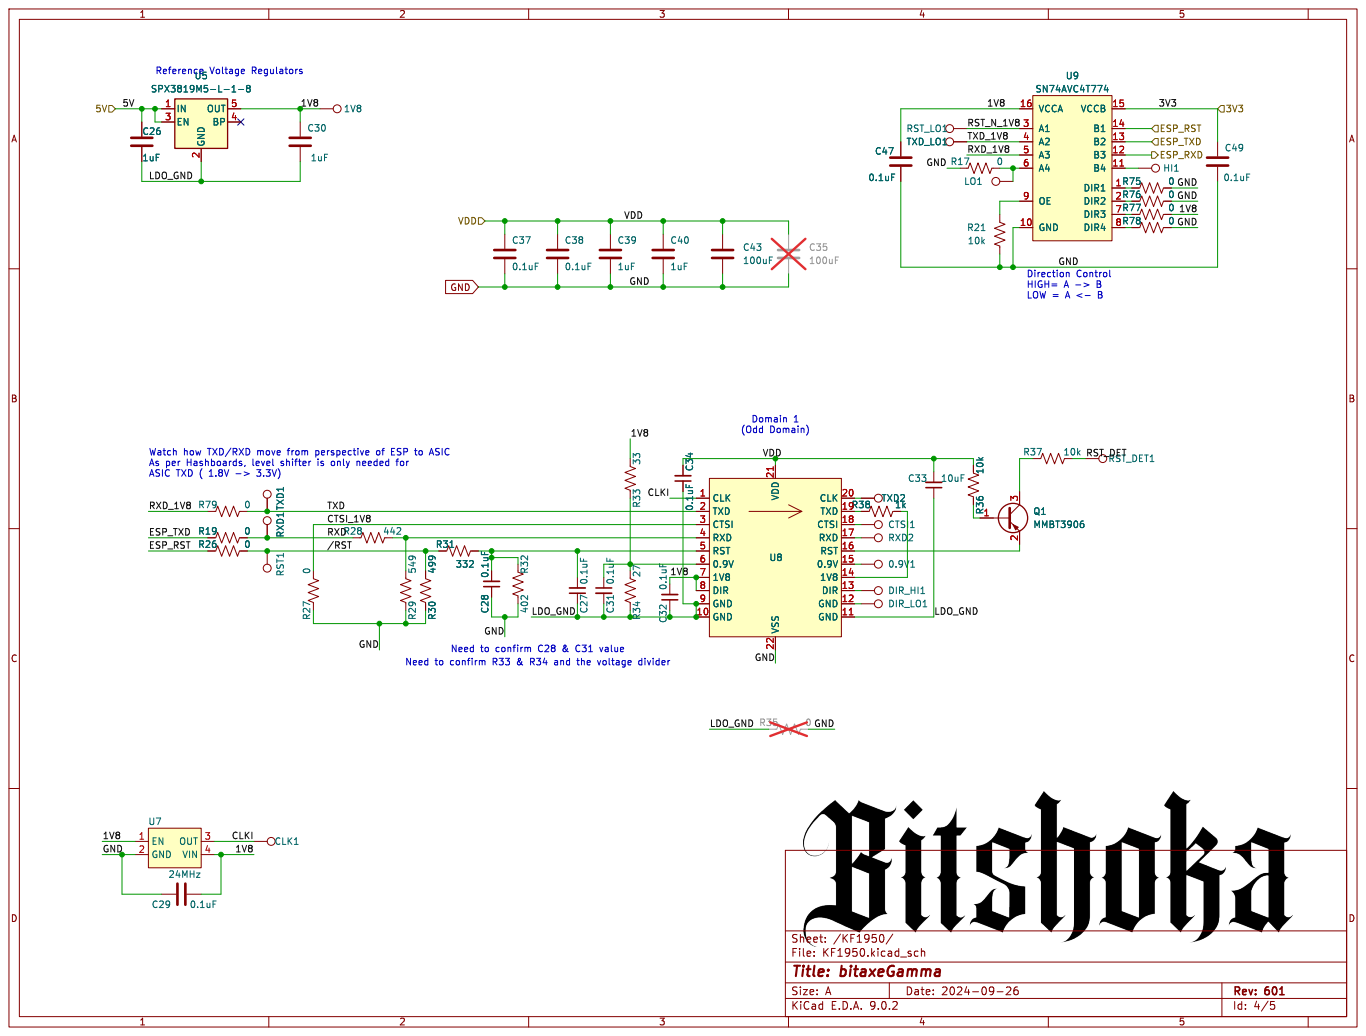
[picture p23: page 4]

3 2 R38 1k TXD2 U8 CLK 1 TXD 2 CTSI 3 RXD 4 RST 5

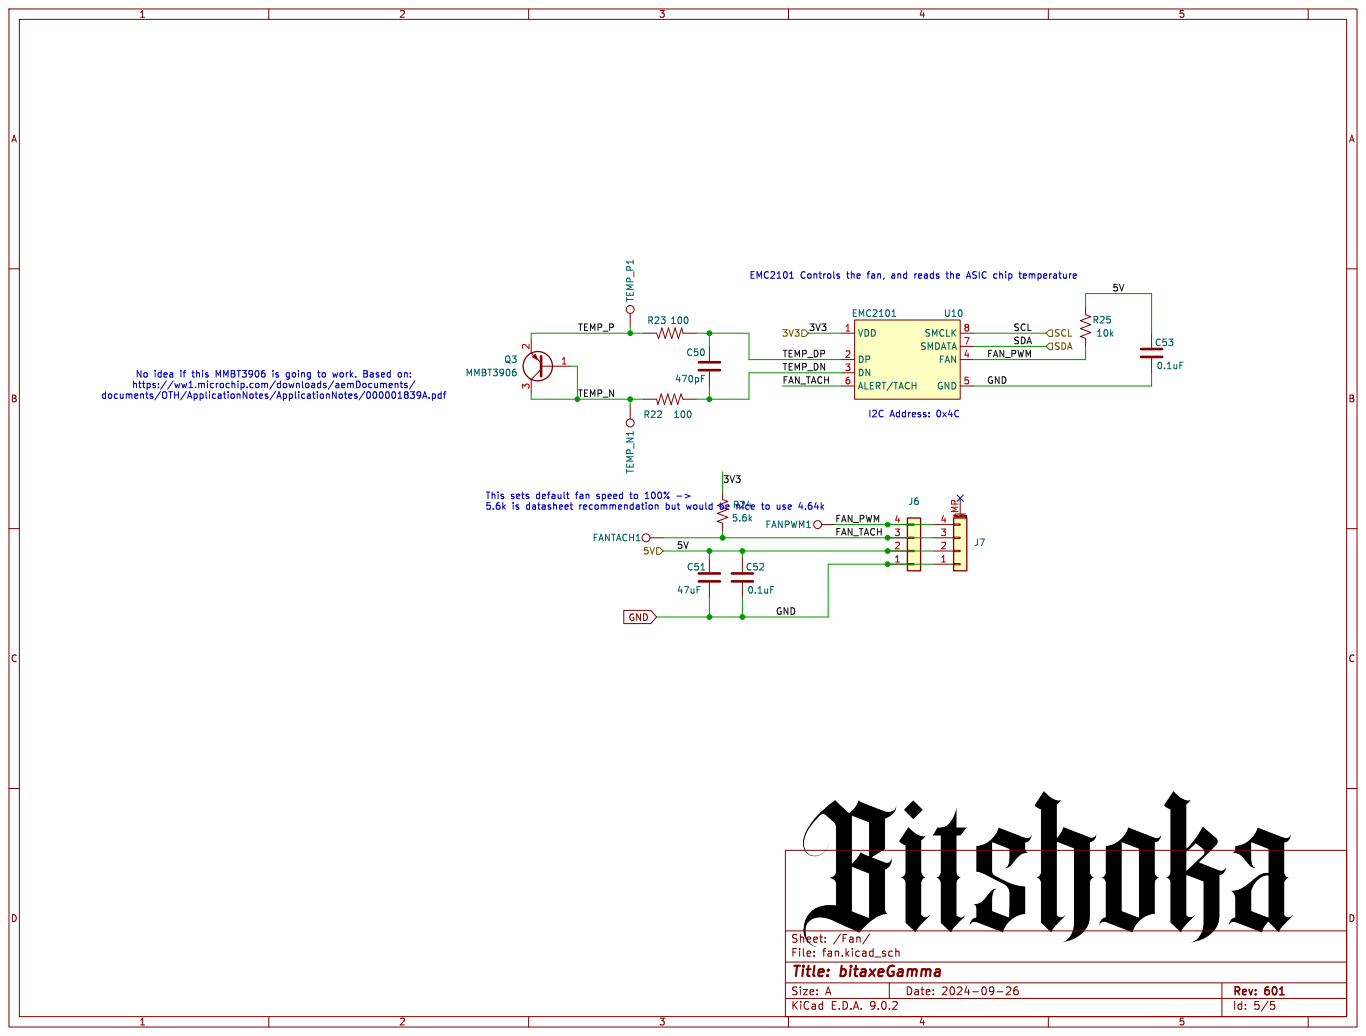
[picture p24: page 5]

No idea if this MMBT3906 is going to work. Based on: https://ww1.microchip.com/downloads/aemDocuments/

File: fan.kicad_sch Sheet: /Fan/ C51

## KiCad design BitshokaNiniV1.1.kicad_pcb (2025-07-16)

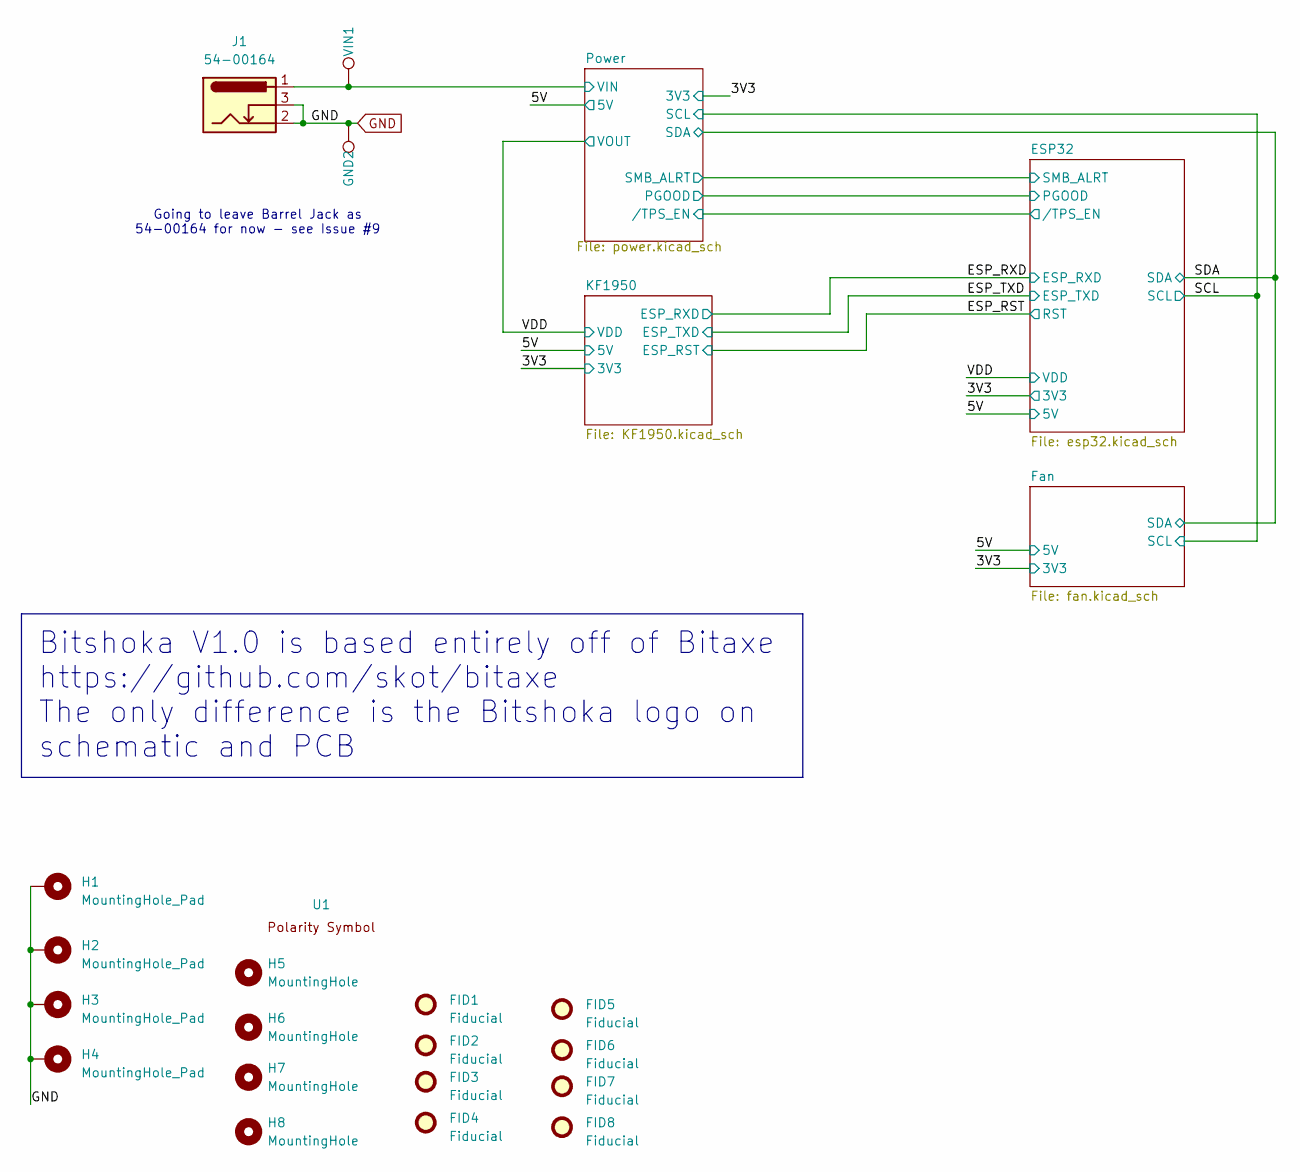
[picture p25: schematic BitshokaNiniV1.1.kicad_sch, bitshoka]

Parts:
FID1, FID2, FID3, FID4, FID5, FID6, FID7, FID8: Fiducial; Fiducial_1mm_Mask2mm
GND2: TestPoint; TestPoint_Pad_D1.5mm
H1, H2, H3, H4: MountingHole_Pad; MountingHole_3mm_Pad_Via
H5, H6, H7, H8: MountingHole; MountingHole_3.5mm
J1: 54-00164; TENSILITY_54-00164; PARTNO 54-00164; LCSC C431534
U1: polarity
VIN1: TestPoint; TestPoint_Pad_D1.5mm

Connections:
/5V: J1.1, VIN1.1; also elsewhere on the board
GND: GND2.1, H1.1, H2.1, H3.1, H4.1, J1.2, J1.3; also elsewhere on the board

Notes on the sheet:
Going to leave Barrel Jack as 54-00164 for now - see Issue #9
Bitshoka V1.0 is based entirely off of Bitaxe https://github.com/skot/bitaxe The only difference is the Bitshoka logo on schematic and PCB

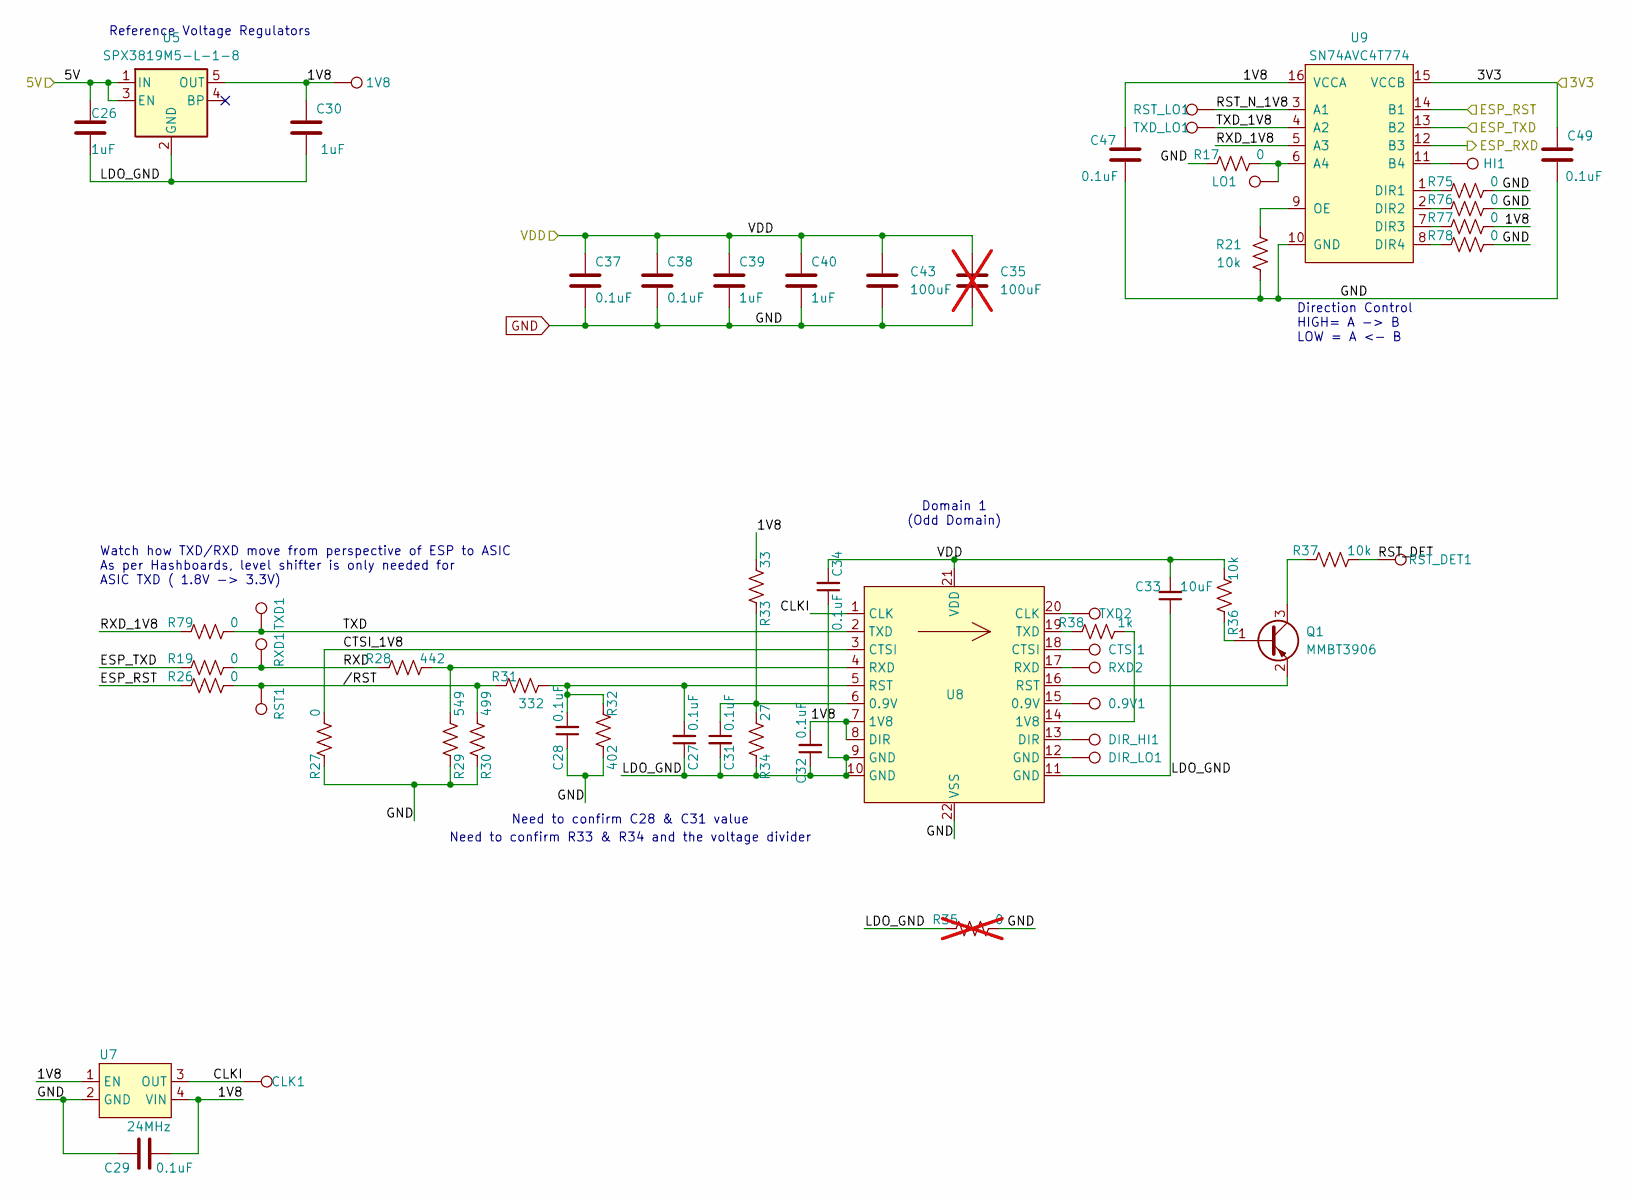
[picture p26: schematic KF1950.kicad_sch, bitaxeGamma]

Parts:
0.9V1: TestPoint; TestPoint_Pad_D1.0mm
1V8: TestPoint; TestPoint_Pad_D1.5mm
C26, C30, C39, C40: 1uF; C_0402_1005Metric; PARTNO EMK105BJ105MV-F
C27, C28, C31, C32, C34: 0.1uF; C_0402_1005Metric
C29, C37, C38, C47, C49: 0.1uF; C_0402_1005Metric; PARTNO CL05A104KO5NNNC
C33: 10uF; C_0805_2012Metric
C35: 100uF; C_1206_3216Metric; not fitted
C43: 100uF; C_1206_3216Metric
CLK1: TestPoint; TestPoint_Pad_D1.5mm
CTSI1: TestPoint; TestPoint_Pad_D1.0mm
DIR_HI1: TestPoint; TestPoint_Pad_D1.0mm
DIR_LO1: TestPoint; TestPoint_Pad_D1.0mm
HI1: TestPoint; TestPoint_Pad_D1.5mm
LO1: TestPoint; TestPoint_Pad_D1.5mm
Q1: MMBT3906; SOT-23
R17, R19, R26, R27, R79: 0; R_0402_1005Metric
R21: 10k; R_0402_1005Metric; PARTNO RC0402FR-0720KL
R28: 442; R_0402_1005Metric
R29: 549; R_0402_1005Metric
R30: 499; R_0402_1005Metric
R31: 332; R_0402_1005Metric
R32: 402; R_0402_1005Metric
R33: 33; R_0402_1005Metric
R34: 27; R_0402_1005Metric
R35: 0; R_0402_1005Metric; not fitted
R36, R37: 10k; R_0402_1005Metric
R38: 1k; R_0402_1005Metric
R75, R76, R77, R78: 0; R_0402_1005Metric; PARTNO RC0402FR-0720KL
RST1: TestPoint; TestPoint_Pad_D1.5mm
RST_DET1: TestPoint; TestPoint_Pad_D1.5mm
RST_LO1: TestPoint; TestPoint_Pad_D1.5mm
RXD1: TestPoint; TestPoint_Pad_D1.5mm
RXD2: TestPoint; TestPoint_Pad_D1.0mm
TXD1: TestPoint; TestPoint_Pad_D1.5mm
TXD2: TestPoint; TestPoint_Pad_D1.0mm
TXD_LO1: TestPoint; TestPoint_Pad_D1.5mm
U5: SPX3819M5-L-1-8; SOT-23-5
U7: 24MHz; SMD3225-4P; PARTNO SX3M25.000E20F30THN; LCSC C5137262
U8: KF1950
U9: SN74AVC4T774; TSSOP-16_4.4x5mm_P0.65mm; PARTNO SN74AVC4T774PWR

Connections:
/3V3: C49.1, U9.15 (VCCB); also elsewhere on the board
/5V: C26.1, U5.1 (IN), U5.3 (EN); also elsewhere on the board
/ESP_RST: R26.1, U9.14 (B1); also elsewhere on the board
/ESP_RXD: U9.12 (B3); also elsewhere on the board
/ESP_TXD: R19.1, U9.13 (B2); also elsewhere on the board
/KF1950/1V8: 1V8.1, C29.2, C30.1, C32.2, C47.1, R33.2, R77.1, U5.5 (OUT), U7.1 (EN), U7.4 (VIN), U8.7 (1V8), U8.8 (DIR), U9.16 (VCCA)
/KF1950/CLKI: CLK1.1, U7.3 (OUT), U8.1 (CLK)
/KF1950/CTSI_1V8: R27.2, U8.3 (CTSI)
/KF1950/LDO_GND: C26.2, C27.1, C30.2, C31.2, C32.1, C33.1, C34.1, R34.1, R35.1, U5.2 (GND), U8.9 (GND), U8.10 (GND), U8.11 (GND)
/KF1950/RST_DET: R37.2, RST_DET1.1
/KF1950/RST_N_1V8: RST_LO1.1, U9.3 (A1)
/KF1950/RXD: R19.2, R28.1, RXD1.1
/KF1950/RXD_1V8: R79.1, U9.5 (A3)
/KF1950/TXD: R79.2, TXD1.1, U8.2 (TXD)
/KF1950/TXD_1V8: TXD_LO1.1, U9.4 (A2)
/KF1950//RST: R26.2, R30.2, R31.1, RST1.1
/VDD: C33.2, C34.2, C35.1, C37.1, C38.1, C39.1, C40.1, C43.1, R36.1, U8.21 (VDD); also elsewhere on the board
GND: C28.1, C29.1, C35.2, C37.2, C38.2, C39.2, C40.2, C43.2, C47.2, C49.2, R17.1, R21.1, R27.1, R29.1, R30.1, R32.2, R35.2, R75.1, R76.1, R78.1, U7.2 (GND), U8.22 (VSS), U9.10 (GND); also elsewhere on the board
unnamed: 0.9V1.1, U8.15 (0.9V)
unnamed: C27.2, C28.2, R31.2, R32.1, U8.5 (RST)
unnamed: C31.1, R33.1, R34.2, U8.6 (0.9V)
unnamed: CTSI1.1, U8.18 (CTSI)
unnamed: DIR_HI1.1, U8.13 (DIR)
unnamed: DIR_LO1.1, U8.12 (GND)
unnamed: Q1.1 (B), R36.2
unnamed: Q1.3 (C), R37.1
unnamed: Q1.2 (E), U8.16 (RST)
unnamed: R28.2, R29.2, U8.4 (RXD)
unnamed: R38.1, U8.14 (1V8)
unnamed: R38.2, U8.19 (TXD)
unnamed: RXD2.1, U8.17 (RXD)
unnamed: TXD2.1, U8.20 (CLK)
unnamed: LO1.1, R17.2, U9.6 (A4)
unnamed: HI1.1, U9.11 (B4)
unnamed: R75.2, U9.1 (DIR1)
unnamed: R76.2, U9.2 (DIR2)
unnamed: R77.2, U9.7 (DIR3)
unnamed: R78.2, U9.8 (DIR4)
unnamed: R21.2, U9.9 (OE)

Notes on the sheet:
Reference Voltage Regulators
Need to confirm C28 & C31 value
Domain 1 (Odd Domain)
Direction Control HIGH= A -> B LOW = A <- B
Watch how TXD/RXD move from perspective of ESP to ASIC As per Hashboards, level shifter is only needed for ASIC TXD ( 1.8V -> 3.3V)
Need to confirm R33 & R34 and the voltage divider

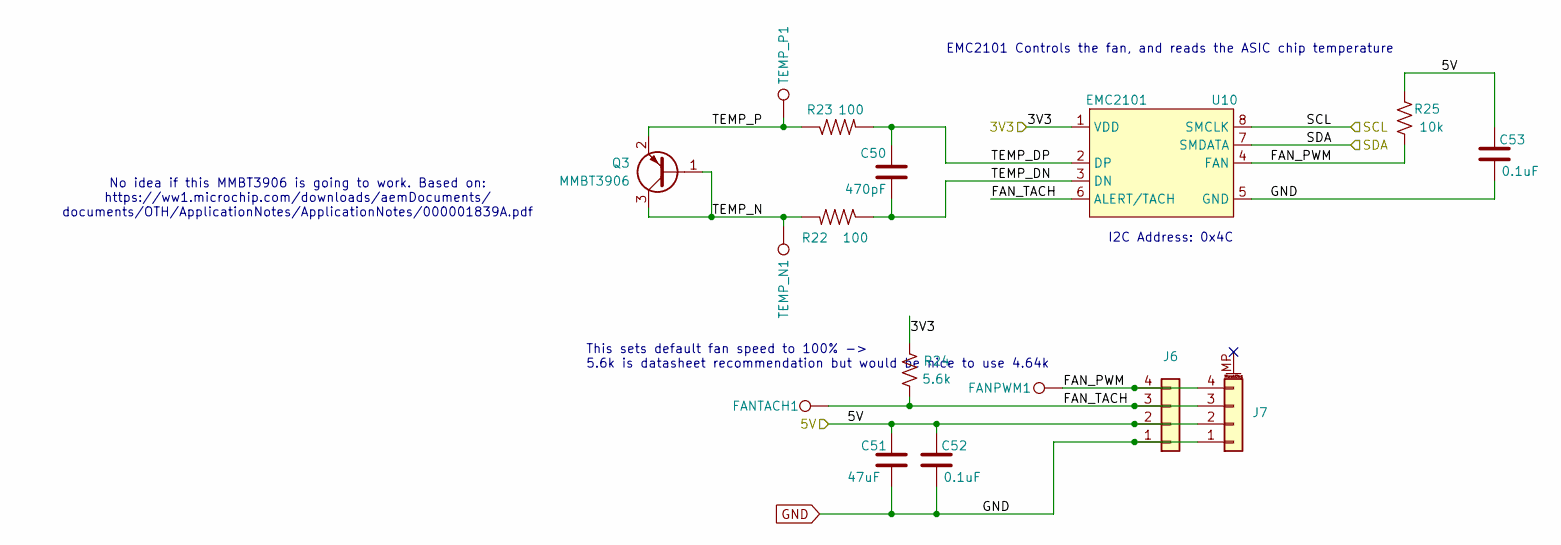
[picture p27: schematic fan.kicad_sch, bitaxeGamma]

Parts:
C50: 470pF; C_0402_1005Metric; PARTNO CL05B471KB5NNNC
C51: 47uF; C_1210_3225Metric; PARTNO CL32A476KOJNNNE
C52, C53: 0.1uF; C_0402_1005Metric; PARTNO CL05A104KO5NNNC
FANPWM1: TestPoint; TestPoint_Pad_D1.5mm
FANTACH1: TestPoint; TestPoint_Pad_D1.5mm
J6: Conn_01x04; 470531000; PARTNO 0470531000
J7: Conn_01x04; JST_SH_BM04B-SRSS-TB_1x04-1MP_P1.00mm_Vertical
Q3: MMBT3906; SOT-23
R22, R23: 100; R_0402_1005Metric; PARTNO RC0402FR-07100RL
R24: 5.6k; R_0402_1005Metric; PARTNO RC0402FR-135K6L
R25: 10k; R_0402_1005Metric; PARTNO RC0402JR-0710KL
TEMP_N1: TestPoint; TestPoint_Pad_D1.5mm
TEMP_P1: TestPoint; TestPoint_Pad_D1.5mm
U10: EMC2101; TSSOP-8_3x3mm_P0.65mm; PARTNO EMC2101-R-ACZL-TR

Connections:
/3V3: R24.2, U10.1 (VDD); also elsewhere on the board
/5V: C51.1, C52.1, C53.1, J6.2, J7.2, R25.2; also elsewhere on the board
/Fan/FAN_PWM: FANPWM1.1, J6.4, J7.4, R25.1, U10.4 (FAN)
/Fan/FAN_TACH: FANTACH1.1, J6.3, J7.3, R24.1, U10.6 (ALERT/TACH)
/Fan/TEMP_DN: C50.2, R22.1, U10.3 (DN)
/Fan/TEMP_DP: C50.1, R23.2, U10.2 (DP)
/Fan/TEMP_N: Q3.1 (B), Q3.3 (C), R22.2, TEMP_N1.1
/Fan/TEMP_P: Q3.2 (E), R23.1, TEMP_P1.1
/SCL: U10.8 (SMCLK); also elsewhere on the board
/SDA: U10.7 (SMDATA); also elsewhere on the board
GND: C51.2, C52.2, C53.2, J6.1, J7.1, U10.5 (GND); also elsewhere on the board

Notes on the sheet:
EMC2101 Controls the fan, and reads the ASIC chip temperature
This sets default fan speed to 100% -> 5.6k is datasheet recommendation but would be nice to use 4.64k
No idea if this MMBT3906 is going to work. Based on: https://ww1.microchip.com/downloads/aemDocuments/ documents/OTH/ApplicationNotes/ApplicationNotes/000001839A.pdf
I2C Address: 0x4C

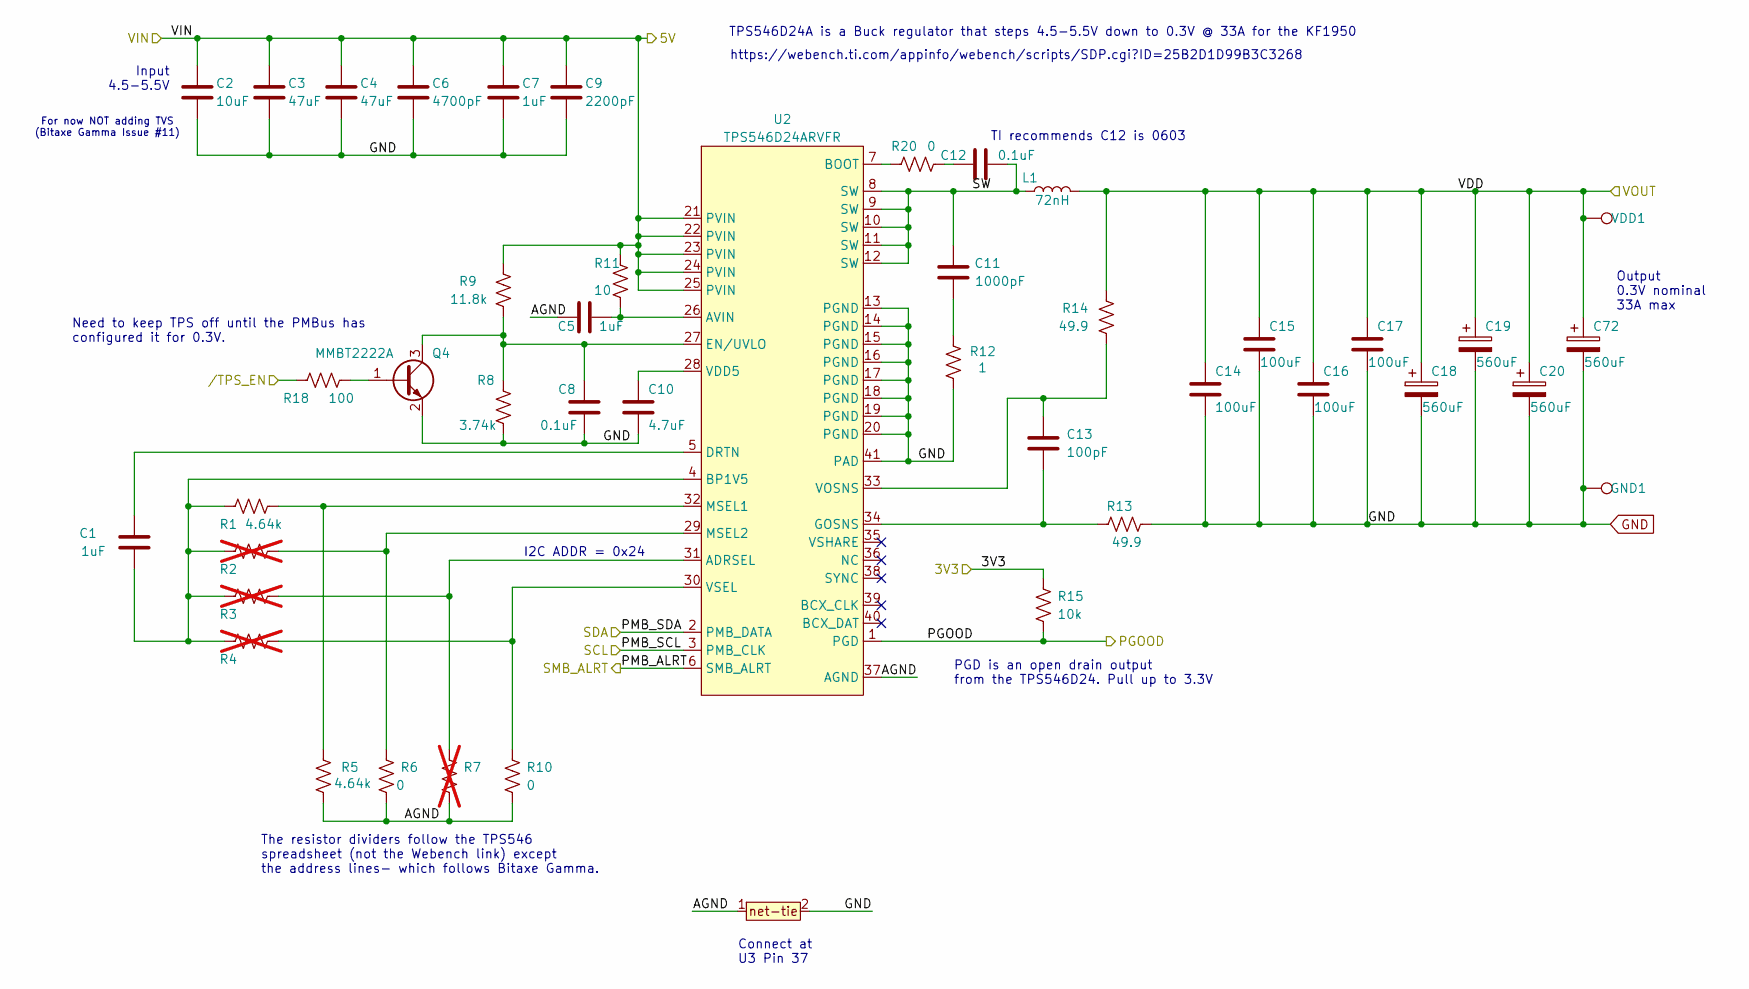
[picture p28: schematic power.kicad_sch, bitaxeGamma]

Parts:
C1, C5, C7: 1uF; C_0402_1005Metric; PARTNO EMK105BJ105MV-F
C2: 10uF; C_0805_2012Metric; PARTNO CL21A106KOQNNNE
C3, C4: 47uF; C_1210_3225Metric; PARTNO CL32A476KOJNNNE
C6: 4700pF; C_0402_1005Metric; PARTNO GRM155R71E472KA01D
C8: 0.1uF; C_0402_1005Metric; PARTNO CL05A104KO5NNNC
C9: 2200pF; C_0402_1005Metric; PARTNO GRM155R61H222KA01D
C10: 4.7uF; C_0402_1005Metric; PARTNO GRM155R61A475MEAAD
C11: 1000pF; C_0402_1005Metric; PARTNO CC0805KRX7R9BB102
C12: 0.1uF; C_0603_1608Metric; PARTNO CL05A104KO5NNNC
C13: 100pF; C_0402_1005Metric; PARTNO 885012005013
C14: 100uF; C_1206_3216Metric; PARTNO GRM32EC80J107ME20L
C15, C16, C17: 100uF; C_1206_3216Metric
C18, C19, C20, C72: 560uF; EEF-GX; PARTNO EEF-GX0D561R
GND1: TestPoint; TestPoint_Pad_D1.5mm
L1: 72nH; FP0805R1; PARTNO FP0805R1-R07-R
Q4: MMBT2222A; SOT-23
R1: 4.64k; R_0402_1005Metric; PARTNO RC0402FR-078K25L
R2, R3, R4, R7: R_0402_1005Metric; not fitted
R5: 4.64k; R_0402_1005Metric; PARTNO RC0402FR-0714K7L
R6: 0; R_0402_1005Metric; PARTNO RC0402JR-070RL
R8: 3.74k; R_0402_1005Metric; PARTNO RC0402FR-073K74L
R9: 11.8k; R_0402_1005Metric; PARTNO RC0402FR-0711K8L
R10: 0; R_0402_1005Metric; PARTNO RC0402FR-0768K1L
R11: 10; R_0402_1005Metric; PARTNO RC0402FR-0710RL
R12: 1; R_1206_3216Metric; PARTNO CSR1206FT1R00
R13, R14: 49.9; R_0402_1005Metric; PARTNO RC0402FR-0749R9L
R15: 10k; R_0402_1005Metric; PARTNO RC0402JR-0710KL
R18: 100; R_0402_1005Metric; PARTNO RC0402FR-078K25L
R20: 0; R_0402_1005Metric; PARTNO CSR1206FT1R00
T1: net-tie; NetTie-0.25mm
U2: TPS546D24ARVFR; LQFN40-CLIP; PARTNO TPS546D24ARVFR
VDD1: TestPoint; TestPoint_Pad_D1.5mm

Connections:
/3V3: R15.2; also elsewhere on the board
/5V: C2.1, C3.1, C4.1, C6.1, C7.1, C9.1, R9.1, R11.1, U2.21 (PVIN), U2.22 (PVIN), U2.23 (PVIN), U2.24 (PVIN), U2.25 (PVIN); also elsewhere on the board
/ESP32//TPS_EN: R18.1; also elsewhere on the board
/Power/AGND: C5.2, R5.1, R6.2, R7.2, R10.2, T1.1, U2.37 (AGND)
/Power/PGOOD: R15.1, U2.1 (PGD); also elsewhere on the board
/Power/PMB_ALRT: U2.6 (SMB_ALRT); also elsewhere on the board
/Power/SW: C11.2, C12.2, L1.1, U2.8 (SW), U2.9 (SW), U2.10 (SW), U2.11 (SW), U2.12 (SW)
/SCL: U2.3 (PMB_CLK); also elsewhere on the board
/SDA: U2.2 (PMB_DATA); also elsewhere on the board
/VDD: C14.1, C15.1, C16.1, C17.1, C18.1, C19.1, C20.1, C72.1, L1.2, R14.1, VDD1.1; also elsewhere on the board
GND: C2.2, C3.2, C4.2, C6.2, C7.2, C8.2, C9.2, C10.2, C14.2, C15.2, C16.2, C17.2, C18.2, C19.2, C20.2, C72.2, GND1.1, Q4.2 (E), R8.2, R12.1, R13.2, T1.2, U2.13 (PGND), U2.14 (PGND), U2.15 (PGND), U2.16 (PGND), U2.17 (PGND), U2.18 (PGND), U2.19 (PGND), U2.20 (PGND), U2.41 (PAD); also elsewhere on the board
unnamed: C11.1, R12.2
unnamed: C12.1, R20.1
unnamed: Q4.1 (B), R18.2
unnamed: C8.1, Q4.3 (C), R8.1, R9.2, U2.27 (EN/UVLO)
unnamed: R3.2, R7.1, U2.31 (ADRSEL)
unnamed: C5.1, R11.2, U2.26 (AVIN)
unnamed: R20.2, U2.7 (BOOT)
unnamed: C1.2, R1.1, R2.1, R3.1, R4.1, U2.4 (BP1V5)
unnamed: C1.1, U2.5 (DRTN)
unnamed: C13.2, R13.1, U2.34 (GOSNS)
unnamed: R1.2, R5.2, U2.32 (MSEL1)
unnamed: R2.2, R6.1, U2.29 (MSEL2)
unnamed: C10.1, U2.28 (VDD5)
unnamed: C13.1, R14.2, U2.33 (VOSNS)
unnamed: R4.2, R10.1, U2.30 (VSEL)

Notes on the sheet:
Input 4.5-5.5V
https://webench.ti.com/appinfo/webench/scripts/SDP.cgi?ID=25B2D1D99B3C3268
Need to keep TPS off until the PMBus has configured it for 0.3V.
The resistor dividers follow the TPS546 spreadsheet (not the Webench link) except the address lines- which follows Bitaxe Gamma.
PGD is an open drain output from the TPS546D24. Pull up to 3.3V
For now NOT adding TVS (Bitaxe Gamma Issue #11)
I2C ADDR = 0x24
TPS546D24A is a Buck regulator that steps 4.5-5.5V down to 0.3V @ 33A for the KF1950
TI recommends C12 is 0603
Output 0.3V nominal 33A max
Connect at U3 Pin 37

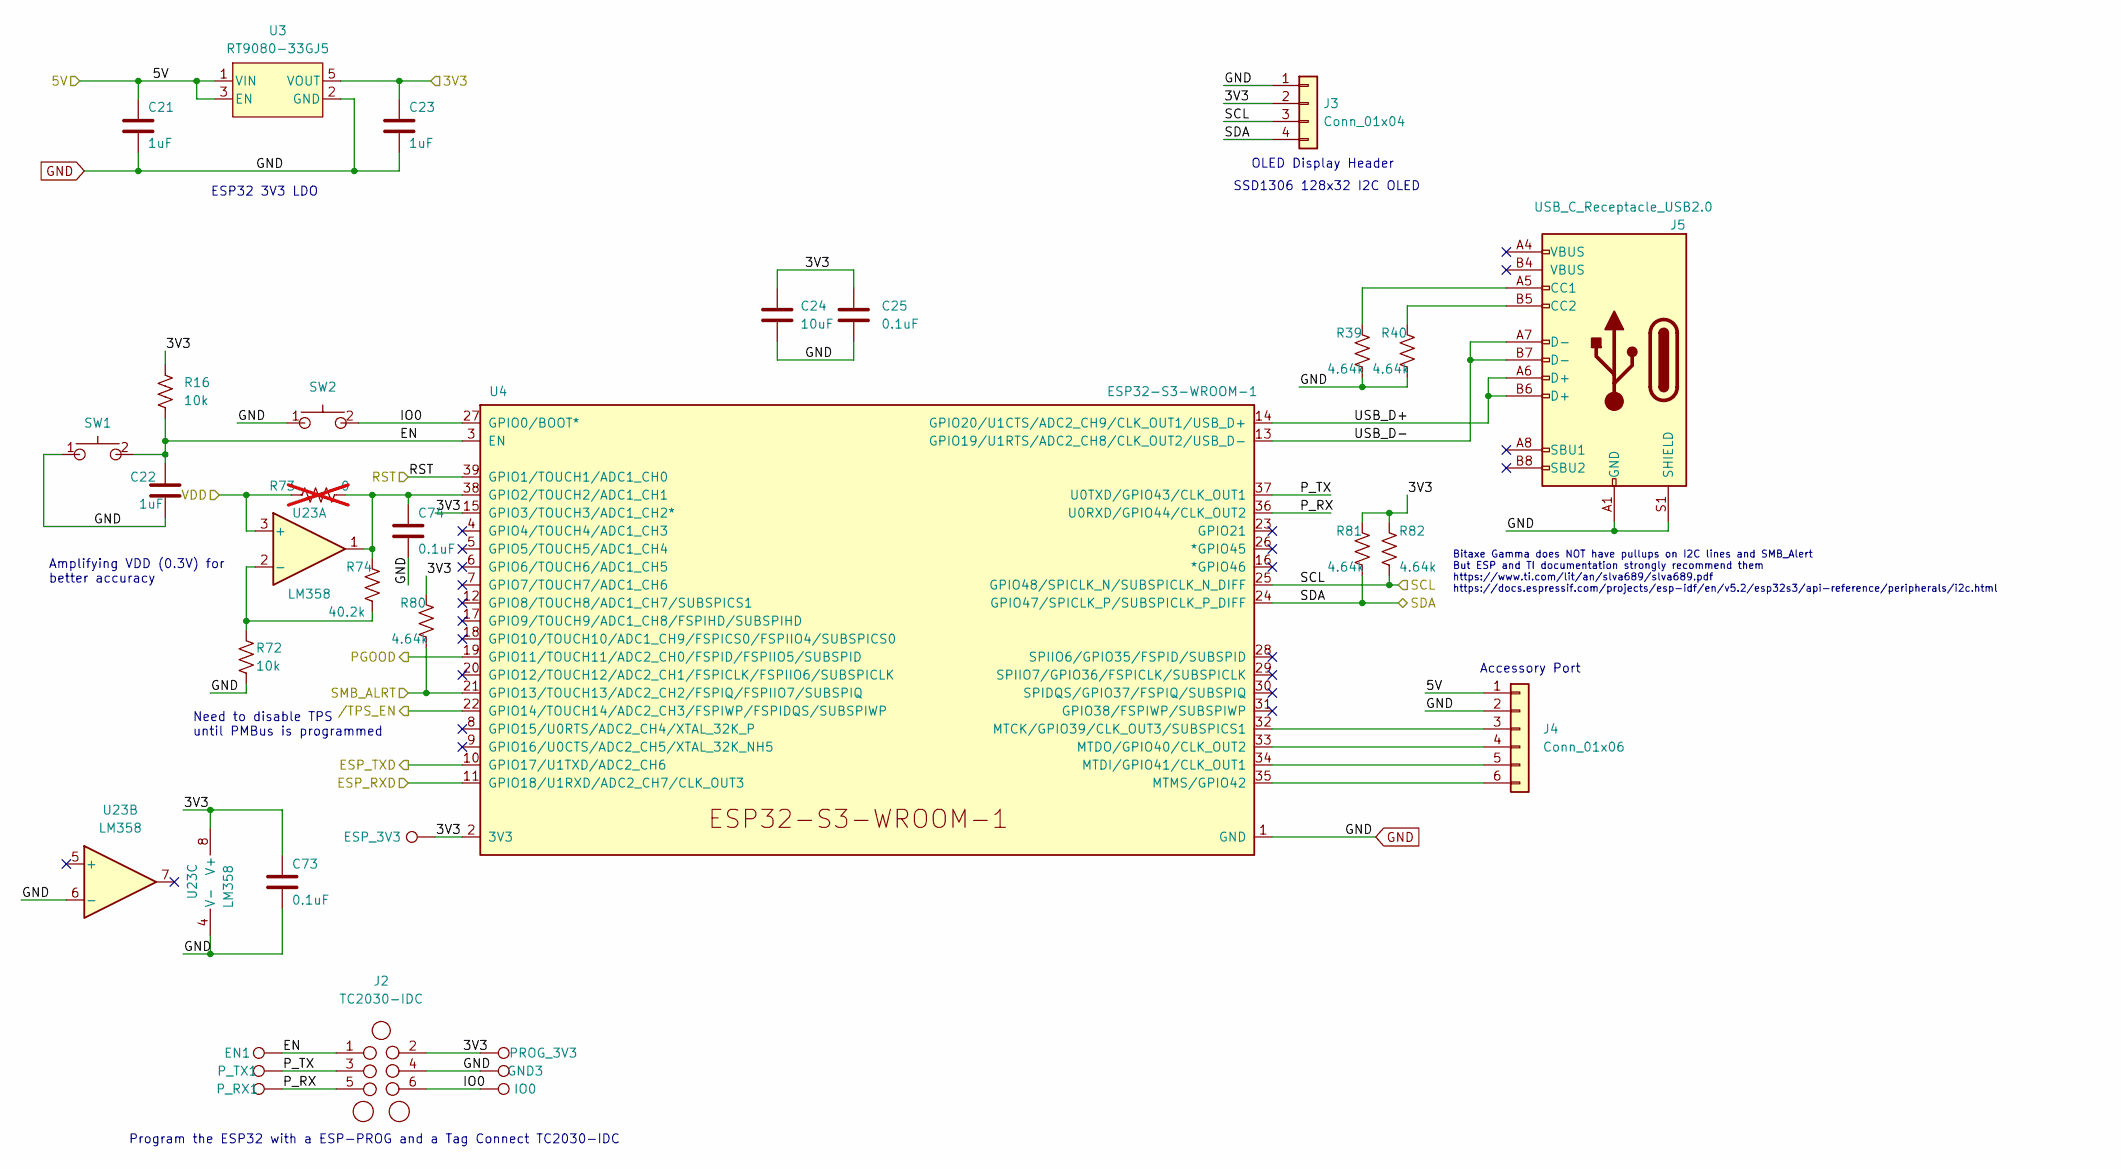
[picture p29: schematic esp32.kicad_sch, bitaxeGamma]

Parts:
C21, C22, C23: 1uF; C_0402_1005Metric; PARTNO EMK105BJ105MV-F
C24: 10uF; C_0805_2012Metric; PARTNO CL21A106KOQNNNE
C25: 0.1uF; C_0402_1005Metric; PARTNO CL05A104KO5NNNC
C73, C74: 0.1uF; C_0402_1005Metric; PARTNO EMK105BJ105MV-F
EN1: TestPoint; TestPoint_Pad_D1.5mm
ESP_3V3: TestPoint; TestPoint_Pad_D1.5mm
GND3: TestPoint; TestPoint_Pad_D1.5mm
IO0: TestPoint; TestPoint_Pad_D1.5mm
J2: TC2030-IDC; Tag-Connect_TC2030-IDC-NL_2x03_P1.27mm_Vertical
J3: Conn_01x04; PinHeader_1x04_P2.54mm_Vertical_shifted
J4: Conn_01x06; PinHeader_1x06_P2.54mm_Vertical
J5: USB_C_Receptacle_USB2.0; USB_C_Receptacle_GCT_USB4105-xx-A; PARTNO USB4105-GF-A
PROG_3V3: TestPoint; TestPoint_Pad_D1.5mm
P_RX1: TestPoint; TestPoint_Pad_D1.5mm
P_TX1: TestPoint; TestPoint_Pad_D1.5mm
R16, R72: 10k; R_0402_1005Metric; PARTNO RC0402JR-0710KL
R39, R40, R80, R81, R82: 4.64k; R_0402_1005Metric; PARTNO RC0402JR-0710KL
R73: 0; R_0402_1005Metric; PARTNO RC0402JR-0710KL; not fitted
R74: 40.2k; R_0402_1005Metric; PARTNO RC0402JR-0710KL
SW1, SW2: GT-TC029B-H025-L1N; SW_CS1213AGF260_CRS; PARTNO CS1213AGF260
U3: RT9080-33GJ5; PARTNO RT9080-33GJ5
U4: ESP32-S3-WROOM-1; PARTNO ESP32-S3-WROOM-1-N16R8
U23: LM358; TSSOP-8_4.4x3mm_P0.65mm

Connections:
/3V3: C23.1, C24.1, C25.1, C73.1, ESP_3V3.1, J2.2, J3.2, PROG_3V3.1, R16.1, R80.1, R81.1, R82.1, U3.5 (VOUT), U4.2 (3V3), U4.15 (GPIO3/TOUCH3/ADC1_CH2*), U23.8 (V+); also elsewhere on the board
/5V: C21.1, J4.1, U3.1 (VIN), U3.3 (EN); also elsewhere on the board
/ESP32/EN: C22.1, EN1.1, J2.1, R16.2, SW1.2, U4.3 (EN)
/ESP32/IO0: IO0.1, J2.6, SW2.2, U4.27 (GPIO0/BOOT*)
/ESP32/P_RX: J2.5, P_RX1.1, U4.36 (U0RXD/GPIO44/CLK_OUT2)
/ESP32/P_TX: J2.3, P_TX1.1, U4.37 (U0TXD/GPIO43/CLK_OUT1)
/ESP32/USB_D+: J5.A6 (D+), J5.B6 (D+), U4.14 (GPIO20/U1CTS/ADC2_CH9/CLK_OUT1/USB_D+)
/ESP32/USB_D-: J5.A7 (D-), J5.B7 (D-), U4.13 (GPIO19/U1RTS/ADC2_CH8/CLK_OUT2/USB_D-)
/ESP32//TPS_EN: U4.22 (GPIO14/TOUCH14/ADC2_CH3/FSPIWP/FSPIDQS/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); also elsewhere on the board
/ESP_RST: U4.39 (GPIO1/TOUCH1/ADC1_CH0); also elsewhere on the board
/ESP_RXD: U4.11 (GPIO18/U1RXD/ADC2_CH7/CLK_OUT3); also elsewhere on the board
/ESP_TXD: U4.10 (GPIO17/U1TXD/ADC2_CH6); also elsewhere on the board
/Power/PGOOD: U4.19 (GPIO11/TOUCH11/ADC2_CH0/FSPID/FSPIIO5/S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); also elsewhere on the board
/Power/PMB_ALRT: R80.2, U4.21 (GPIO13/TOUCH13/ADC2_CH2/FSPIQ/FSPIIO7/S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); also elsewhere on the board
/SCL: J3.3, R82.2, U4.25 (GPIO48/SPICLK_N/SUBSPICLK_N_DIFF); also elsewhere on the board
/SDA: J3.4, R81.2, U4.24 (GPIO47/SPICLK_P/SUBSPICLK_P_DIFF); also elsewhere on the board
/VDD: R73.1, U23.3 (+); also elsewhere on the board
GND: C21.2, C22.2, C23.2, C24.2, C25.2, C73.2, C74.2, GND3.1, J2.4, J3.1, J4.2, J5.A1 (GND), J5.B1 (GND), J5.S1 (SHIELD), R39.2, R40.2, R72.1, SW1.1, SW2.1, U3.2 (GND), U4.1 (GND), U4.40 (GND), U4.41 (GND), U23.4 (V-), U23.6 (-); also elsewhere on the board
unnamed: J4.3, U4.32 (MTCK/GPIO39/CLK_OUT3/SUBSPICS1)
unnamed: J4.4, U4.33 (MTDO/GPIO40/CLK_OUT2)
unnamed: J4.5, U4.34 (MTDI/GPIO41/CLK_OUT1)
unnamed: J4.6, U4.35 (MTMS/GPIO42)
unnamed: J5.A5 (CC1), R39.1
unnamed: J5.B5 (CC2), R40.1
unnamed: C74.1, R73.2, R74.1, U4.38 (GPIO2/TOUCH2/ADC1_CH1), U23.1
unnamed: R72.2, R74.2, U23.2 (-)

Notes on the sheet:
Accessory Port
ESP32 3V3 LDO
Program the ESP32 with a ESP-PROG and a Tag Connect TC2030-IDC
Bitaxe Gamma does NOT have pullups on I2C lines and SMB_Alert But ESP and TI documentation strongly recommend them https://www.ti.com/lit/an/slva689/slva689.pdf https://docs.espressif.com/projects/esp-idf/en/v5.2/esp32s3/api-reference/peripherals/i2c.html
Amplifying VDD (0.3V) for better accuracy
SSD1306 128x32 I2C OLED
Need to disable TPS until PMBus is programmed
OLED Display Header

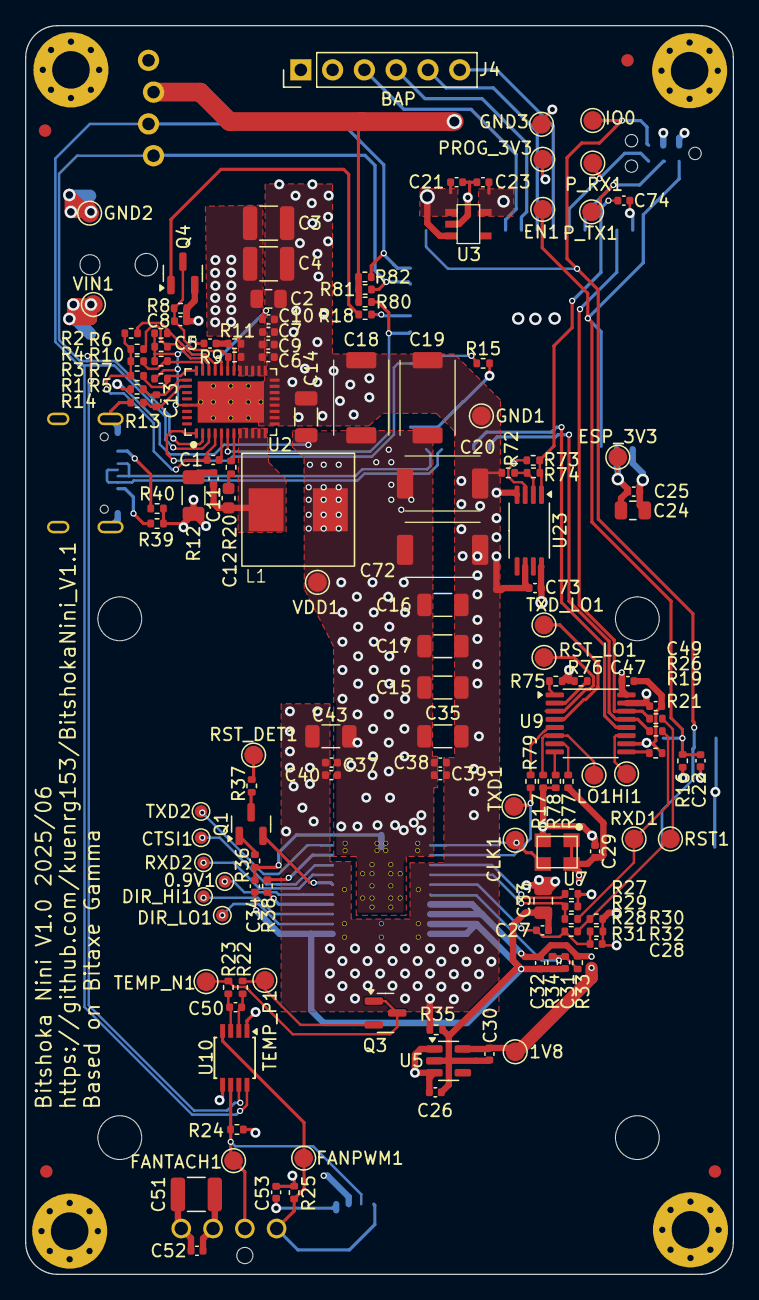
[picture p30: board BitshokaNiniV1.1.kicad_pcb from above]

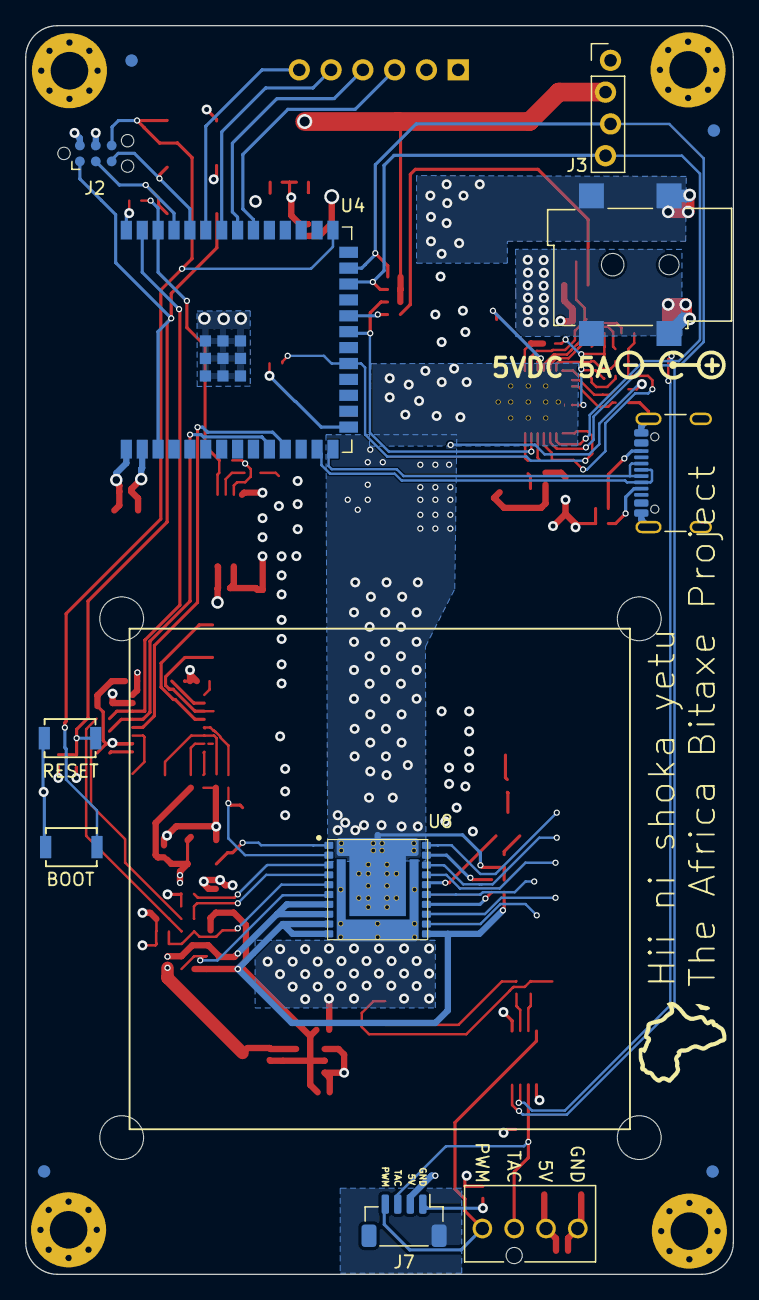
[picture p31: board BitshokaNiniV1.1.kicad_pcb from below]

Board: 4 copper layers, 56.5 x 99.8 mm, 171 parts (15 on the bottom side), 81 nets.

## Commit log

2025-06-05 First Draft
    First draft of Bitshoka Nini
    A Bitaxe Gamma based miner with Whatsminer KF1950 ASIC
    Schematic needs some of the comms lines connected
    Layout needs placement and routing of the new Rs n Cs that came with the KF1950
    [21-0164B_L622-1_MXM.step, 2R5TPE220MAFB.step, 470531000.stp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]
2025-06-12 All components placed
    Went through TI schematic and layout checklist.
    All components placed and initial DRC
    Need thermal vias on KF1950 and also better layout (so not so many errors)
    Need to do silk
    [BitshokaNiniV1.1.kicad_pcb, BitshokaNiniV1.1.kicad_sch, KF1950.kicad_sch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]
2025-06-13 Silk Done
    Still need to fix up heatsink vias on ASIC and paste layer for thermal
    [BitshokaNiniV1.1.kicad_pcb, KF1950.kicad_sch, fan.kicad_sch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]
2025-06-17 PCB fixes
    Fixed up KF1950 footprint
    Added heatsinking to the bottom
    [BitshokaNiniV1.1.kicad_pcb, BitshokaNiniV1.1.kicad_sch, power.kicad_sch]
2025-06-20 Manfacturing prep
    Add part numbers and did initial BOM optimization (Hope to do more after testing)
    Created Manufacturing files
    [BitshokaNiniV1.1-B_Cu.gbr, BitshokaNiniV1.1-B_Mask.gbr, BitshokaNiniV1.1-B_Paste.gbr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]
2025-07-04 Addressed Bitaxe Gamma Issues
    - moved Fan caps
    - added USB CC1 & CC2 pulldowns
    - (I2C pullups were already done)
    - reviewed but so far did not address any of the other issues/bugs
    [BitshokaNiniV1.1.kicad_pcb, BitshokaNiniV1.1.kicad_sch, BitshokaNiniV1.1.ods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]
2025-07-04 Forgot to update Manufacturing Outputs / Gerbers
    - Added Gerbers
    - Add PDF of schematic
    [BitshokaNiniV1.1-B_Cu.gbr, BitshokaNiniV1.1-B_Mask.gbr, BitshokaNiniV1.1-B_Paste.gbr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]
2025-07-16 New Inductor & BOM fix
    Changed the inductor and cleaned up files for JLCPCB order.
    [BitshokaNiniV1.1-B_Cu.gbr, BitshokaNiniV1.1-B_Mask.gbr, BitshokaNiniV1.1-B_Paste.gbr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]
2025-07-16 Fixed CMOS clock
    [KF1950.kicad_sch]

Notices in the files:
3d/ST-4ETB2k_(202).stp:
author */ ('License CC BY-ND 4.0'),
